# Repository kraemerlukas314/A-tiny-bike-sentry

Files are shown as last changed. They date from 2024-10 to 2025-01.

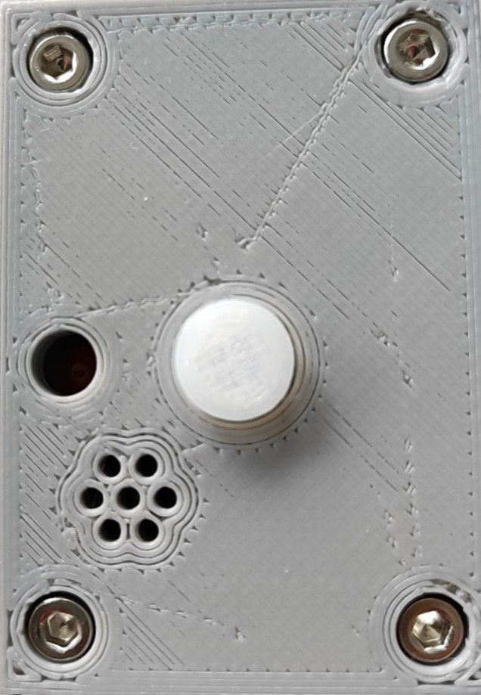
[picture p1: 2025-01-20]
docs/images/sentry.jpg

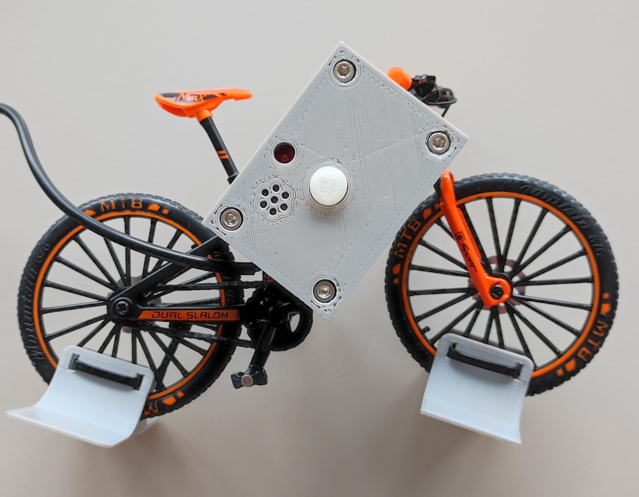
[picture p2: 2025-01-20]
docs/images/bike.jpg

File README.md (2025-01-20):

# A Tiny Bike Sentry

[🇩🇪 Deutsch](#-deutsch) | [🇬🇧 English](#-english)

---

## 📌 Deutsch

### Überblick
A Tiny Bike Sentry ist ein elektronisches Fahrradschloss, das bei Erschütterungen einen optischen und akustischen Alarm auslöst, um Diebstähle zu verhindern. Es basiert auf einem stromsparenden ATtiny85-Mikrocontroller und verwendet eine LED, einen Buzzer, einen Taster und einen Erschütterungssensor.

### Funktionen
- **Erschütterungserkennung**: Erkennt Bewegung mit einem Piezoelement und löst einen Alarm aus.
- **Akustische & optische Warnsignale**: Alarmiert mit einem Buzzer und einer LED.
- **Energiesparmodus**: Minimiert Stromverbrauch durch effiziente Software- und Hardwarearchitektur.
- **Manuelle Aktivierung**: Aktivierung und Deaktivierung per Knopfdruck.

### Hardware
- Mikrocontroller: **ATtiny85** (niedriger Stromverbrauch, kompakte Größe)
- Sensoren: **Piezoelement** zur Erschütterungserkennung
- Aktoren: **LED und Buzzer** zur Alarmierung
- Stromversorgung: **Akku- oder Batteriebetrieb** (optimiert für lange Laufzeit)

### Software
Die Software wurde in **C++** geschrieben und basiert auf einer **zustandsbasierten Programmierung**.
Wichtige Dateien:
- [`main.ino`](src/main/main.ino): Hauptprogramm mit der Zustandsmaschine
- [`Gpio.h`](src/main/Gpio.h) / [`Gpio.cpp`](src/main/Gpio.cpp): Steuerung der Hardware-Pins
- [`Animation.h`](src/main/Animation.h) / [`Animation.cpp`](src/main/Animation.cpp): Verwaltung der LED- und Buzzer-Signale
- [`Timing.h`](src/main/Timing.h) / [`Timing.cpp`](src/main/Timing.cpp): Optimierung der Zeitsteuerung
- [`defines.h`](src/main/defines.h): Konfigurationsdatei mit Schwellenwerten & Pin-Belegung

### Zustandsdiagramm
Das System arbeitet mit einer **Finite State Machine**:
- **Deep Sleep**: Gerät inaktiv, wartet auf Aktivierung
- **Sentry**: Gerät ist scharfgestellt und prüft auf Erschütterungen
- **Attention**: Vorwarnung nach erster Erschütterung
- **Alarm**: Vollständiger Alarmmodus
- **Cooldown**: Nach einer bestimmten Zeit ohne weitere Bewegung geht das System zurück in den Sentry-Modus

(Siehe [`State Machine Graph.pdf`](docs/final%20pdfs/State%20Machine%20Graph.pdf) für visuelle Darstellung)

### Installation & Nutzung
#### Voraussetzungen
- **Arduino IDE oder CLI**
- **ATtiny85 Board-Treiber** (via Board Manager installieren)
- **Arduino as ISP Programmer**

#### Kompilieren & Hochladen
1. ATtiny85 als Board in der Arduino IDE auswählen
2. `Programmer: Arduino as ISP` einstellen
3. Sketch mit `Sketch -> Hochladen über Programmer` übertragen
4. Gerät mit Strom versorgen und testen

### Dokumentation
Detaillierte Informationen zur Implementierung sind in folgenden Dateien enthalten:
- [`Benutzerdokumentation.pdf`](docs/final%20pdfs/A%20tiny%20bike%20sentry%20-%20Benutzerdokumentation.pdf): Anleitung für Endnutzer
- [`Entwicklerdokumentation.pdf`](docs/final%20pdfs/A%20tiny%20bike%20sentry%20-%20Entwicklerdokumentation.pdf): Technische Details & Implementierung
- [`Doxygen refman.pdf`](docs/final%20pdfs/Doxygen%20refman.pdf): Generierte Code-Dokumentation
- [`Präsentation.pdf`](docs/final%20pdfs/A%20tiny%20bike%20sentry%20-%20Präsentation.pdf): Überblick und Projektvorstellung

### Weiterentwicklung
- Implementierung eines **Bluetooth-Moduls** zur Fernsteuerung
- **Akkubetrieb mit Ladeschaltung** für mehr Flexibilität
- **Erweiterte Sicherheitsmechanismen** (z. B. Code-Eingabe oder Smartphone-Authentifizierung)

### Lizenz
Dieses Projekt steht unter der **MIT-Lizenz** – freie Nutzung und Modifikation sind erlaubt.

---

## 📌 English

### Overview
A Tiny Bike Sentry is an electronic bike lock that triggers an optical and acoustic alarm when vibrations are detected, helping to prevent theft. It is based on a low-power ATtiny85 microcontroller and uses an LED, a buzzer, a button, and a vibration sensor.

### Features
- **Vibration detection**: Detects movement with a piezo element and triggers an alarm.
- **Acoustic & optical warning signals**: Alerts with a buzzer and LED.
- **Energy-saving mode**: Minimizes power consumption through an efficient software and hardware architecture.
- **Manual activation**: Activate and deactivate via a button press.

### Hardware
- Microcontroller: **ATtiny85** (low power consumption, compact size)
- Sensors: **Piezo element** for vibration detection
- Actuators: **LED and buzzer** for alarming
- Power supply: **Battery or rechargeable operation** (optimized for long battery life)

### Software
The software is written in **C++** and is based on a **state-based programming** approach.
Key files:
- [`main.ino`](src/main/main.ino): Main program with the state machine
- [`Gpio.h`](src/main/Gpio.h) / [`Gpio.cpp`](src/main/Gpio.cpp): Controls hardware pins
- [`Animation.h`](src/main/Animation.h) / [`Animation.cpp`](src/main/Animation.cpp): Manages LED and buzzer signals
- [`Timing.h`](src/main/Timing.h) / [`Timing.cpp`](src/main/Timing.cpp): Optimizes time control
- [`defines.h`](src/main/defines.h): Configuration file with thresholds & pin assignments

### State Diagram
The system operates with a **Finite State Machine**:
- **Deep Sleep**: Device is inactive, waiting for activation
- **Sentry**: Device is armed and checking for vibrations
- **Attention**: Pre-warning after initial vibration detection
- **Alarm**: Full alarm mode
- **Cooldown**: After a certain time without further movement, the system returns to the Sentry mode

(See [`State Machine Graph.pdf`](docs/final%20pdfs/State%20Machine%20Graph.pdf) for a visual representation)

### Installation & Usage
#### Requirements
- **Arduino IDE or CLI**
- **ATtiny85 board driver** (install via board manager)
- **Arduino as ISP programmer**

#### Compiling & Uploading
1. Select ATtiny85 as board in Arduino IDE
2. Set `Programmer: Arduino as ISP`
3. Upload the sketch using `Sketch -> Upload Using Programmer`
4. Power the device and test

### Documentation
Detailed implementation information can be found in the following files:
- [`Benutzerdokumentation.pdf`](docs/final%20pdfs/A%20tiny%20bike%20sentry%20-%20Benutzerdokumentation.pdf): User manual
- [`Entwicklerdokumentation.pdf`](docs/final%20pdfs/A%20tiny%20bike%20sentry%20-%20Entwicklerdokumentation.pdf): Technical details & implementation
- [`Doxygen refman.pdf`](docs/final%20pdfs/Doxygen%20refman.pdf): Generated code documentation
- [`Präsentation.pdf`](docs/final%20pdfs/A%20tiny%20bike%20sentry%20-%20Präsentation.pdf): Overview and project presentation

### License
This project is released under the **MIT License** – free to use and modify.

---

**Project by Lukas Krämer | Winter Semester 2024**  
[GitHub Repository](https://github.com/kraemerlukas314/A-tiny-bike-sentry)

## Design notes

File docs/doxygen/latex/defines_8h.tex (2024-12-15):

\doxysection{src/main/defines.h File Reference}
\hypertarget{defines_8h}{}\label{defines_8h}\index{src/main/defines.h@{src/main/defines.h}}

This file includes all important declarations and definitions.  

\doxysubsubsection*{Macros}
\begin{DoxyCompactItemize}
\item 
\#define \mbox{\hyperlink{defines_8h_ae70934b3338990d4a3faecf2ee172d92}{PIN\+\_\+\+LED}}~1
\begin{DoxyCompactList}\small\item\em Pin for the LED. \end{DoxyCompactList}\item 
\#define \mbox{\hyperlink{defines_8h_a3be8154d350ce65f5e6c1dfc284700af}{PIN\+\_\+\+BUTTON}}~2
\begin{DoxyCompactList}\small\item\em Pin for the button. \end{DoxyCompactList}\item 
\#define \mbox{\hyperlink{defines_8h_ad67197684098f7e8191189a49b5198cd}{PIN\+\_\+\+PIEZO}}~3
\begin{DoxyCompactList}\small\item\em Pin for the piezo. \end{DoxyCompactList}\item 
\#define \mbox{\hyperlink{defines_8h_a192ea8eaba652d29bfc08675edebb6a2}{PIN\+\_\+\+BUZZER}}~4
\begin{DoxyCompactList}\small\item\em Pin for the button. \end{DoxyCompactList}\item 
\#define \mbox{\hyperlink{defines_8h_a28a3e5097d1f1cac1cd73737434760dc}{CLOCK\+\_\+\+FREQ\+\_\+\+MHZ}}~1
\begin{DoxyCompactList}\small\item\em Selected clock frequency in MHz. \end{DoxyCompactList}\item 
\#define \mbox{\hyperlink{defines_8h_a5be5a63f189faba4da1c6f98d11310c6}{THRESHOLD\+\_\+\+PIEZO}}~30
\begin{DoxyCompactList}\small\item\em Threshold for piezo for movement detection. \end{DoxyCompactList}\item 
\#define \mbox{\hyperlink{defines_8h_ae8df221e4e5e1930a43fb7d2c3944665}{DELAY\+\_\+\+BUTTON\+\_\+\+DEBOUNCE\+\_\+\+MS}}~50
\begin{DoxyCompactList}\small\item\em Button debounce delay. \end{DoxyCompactList}\item 
\#define \mbox{\hyperlink{defines_8h_a253c5c57ad2d67b9d8b6ddb553dde09a}{ALARM\+\_\+\+TOGGLE\+\_\+\+FREQ}}~20
\begin{DoxyCompactList}\small\item\em Frequency for alarm. \end{DoxyCompactList}\item 
\#define \mbox{\hyperlink{defines_8h_a6cd671141c60a732c42f1ad79f1a5890}{DELAY\+\_\+\+PIEZO\+\_\+\+MOVED\+\_\+\+MS}}~500
\begin{DoxyCompactList}\small\item\em When piezo is moved, wait for DELAY\+\_\+\+PIEZO\+\_\+\+MOVED\+\_\+\+MS because it could be just a button press. \end{DoxyCompactList}\item 
\#define \mbox{\hyperlink{defines_8h_a9e1a2184797108f3fd67e0251343d960}{ATTENTION\+\_\+\+COOLDOWN\+\_\+\+MS}}~5000
\begin{DoxyCompactList}\small\item\em Cooldown after which state attention is left again. \end{DoxyCompactList}\item 
\#define \mbox{\hyperlink{defines_8h_a6b3c978dd2a7b246650bb233f2b8e942}{ALARM\+\_\+\+COOLDOWN\+\_\+\+MS}}~5000
\begin{DoxyCompactList}\small\item\em Cooldown after which state alarm is left again. \end{DoxyCompactList}\end{DoxyCompactItemize}

\doxysubsection{Detailed Description}
This file includes all important declarations and definitions. 

\begin{DoxyAuthor}{Author}
Lukas Krämer 
\end{DoxyAuthor}

Definition in file \mbox{\hyperlink{defines_8h_source}{defines.\+h}}.

\doxysubsection{Macro Definition Documentation}
\Hypertarget{defines_8h_a6b3c978dd2a7b246650bb233f2b8e942}\label{defines_8h_a6b3c978dd2a7b246650bb233f2b8e942} 
\index{defines.h@{defines.h}!ALARM\_COOLDOWN\_MS@{ALARM\_COOLDOWN\_MS}}
\index{ALARM\_COOLDOWN\_MS@{ALARM\_COOLDOWN\_MS}!defines.h@{defines.h}}
\doxysubsubsection{\texorpdfstring{ALARM\_COOLDOWN\_MS}{ALARM\_COOLDOWN\_MS}}
{\footnotesize\ttfamily \#define ALARM\+\_\+\+COOLDOWN\+\_\+\+MS~5000}

Cooldown after which state alarm is left again. 

Definition at line \mbox{\hyperlink{defines_8h_source_l00063}{63}} of file \mbox{\hyperlink{defines_8h_source}{defines.\+h}}.

\Hypertarget{defines_8h_a253c5c57ad2d67b9d8b6ddb553dde09a}\label{defines_8h_a253c5c57ad2d67b9d8b6ddb553dde09a} 
\index{defines.h@{defines.h}!ALARM\_TOGGLE\_FREQ@{ALARM\_TOGGLE\_FREQ}}
\index{ALARM\_TOGGLE\_FREQ@{ALARM\_TOGGLE\_FREQ}!defines.h@{defines.h}}
\doxysubsubsection{\texorpdfstring{ALARM\_TOGGLE\_FREQ}{ALARM\_TOGGLE\_FREQ}}
{\footnotesize\ttfamily \#define ALARM\+\_\+\+TOGGLE\+\_\+\+FREQ~20}

Frequency for alarm. 

Definition at line \mbox{\hyperlink{defines_8h_source_l00047}{47}} of file \mbox{\hyperlink{defines_8h_source}{defines.\+h}}.

\Hypertarget{defines_8h_a9e1a2184797108f3fd67e0251343d960}\label{defines_8h_a9e1a2184797108f3fd67e0251343d960} 
\index{defines.h@{defines.h}!ATTENTION\_COOLDOWN\_MS@{ATTENTION\_COOLDOWN\_MS}}
\index{ATTENTION\_COOLDOWN\_MS@{ATTENTION\_COOLDOWN\_MS}!defines.h@{defines.h}}
\doxysubsubsection{\texorpdfstring{ATTENTION\_COOLDOWN\_MS}{ATTENTION\_COOLDOWN\_MS}}
{\footnotesize\ttfamily \#define ATTENTION\+\_\+\+COOLDOWN\+\_\+\+MS~5000}

Cooldown after which state attention is left again. 

Definition at line \mbox{\hyperlink{defines_8h_source_l00058}{58}} of file \mbox{\hyperlink{defines_8h_source}{defines.\+h}}.

\Hypertarget{defines_8h_a28a3e5097d1f1cac1cd73737434760dc}\label{defines_8h_a28a3e5097d1f1cac1cd73737434760dc} 
\index{defines.h@{defines.h}!CLOCK\_FREQ\_MHZ@{CLOCK\_FREQ\_MHZ}}
\index{CLOCK\_FREQ\_MHZ@{CLOCK\_FREQ\_MHZ}!defines.h@{defines.h}}
\doxysubsubsection{\texorpdfstring{CLOCK\_FREQ\_MHZ}{CLOCK\_FREQ\_MHZ}}
{\footnotesize\ttfamily \#define CLOCK\+\_\+\+FREQ\+\_\+\+MHZ~1}

Selected clock frequency in MHz. 

Definition at line \mbox{\hyperlink{defines_8h_source_l00032}{32}} of file \mbox{\hyperlink{defines_8h_source}{defines.\+h}}.

\Hypertarget{defines_8h_ae8df221e4e5e1930a43fb7d2c3944665}\label{defines_8h_ae8df221e4e5e1930a43fb7d2c3944665} 
\index{defines.h@{defines.h}!DELAY\_BUTTON\_DEBOUNCE\_MS@{DELAY\_BUTTON\_DEBOUNCE\_MS}}
\index{DELAY\_BUTTON\_DEBOUNCE\_MS@{DELAY\_BUTTON\_DEBOUNCE\_MS}!defines.h@{defines.h}}
\doxysubsubsection{\texorpdfstring{DELAY\_BUTTON\_DEBOUNCE\_MS}{DELAY\_BUTTON\_DEBOUNCE\_MS}}
{\footnotesize\ttfamily \#define DELAY\+\_\+\+BUTTON\+\_\+\+DEBOUNCE\+\_\+\+MS~50}

Button debounce delay. 

Definition at line \mbox{\hyperlink{defines_8h_source_l00042}{42}} of file \mbox{\hyperlink{defines_8h_source}{defines.\+h}}.

\Hypertarget{defines_8h_a6cd671141c60a732c42f1ad79f1a5890}\label{defines_8h_a6cd671141c60a732c42f1ad79f1a5890} 
\index{defines.h@{defines.h}!DELAY\_PIEZO\_MOVED\_MS@{DELAY\_PIEZO\_MOVED\_MS}}
\index{DELAY\_PIEZO\_MOVED\_MS@{DELAY\_PIEZO\_MOVED\_MS}!defines.h@{defines.h}}
\doxysubsubsection{\texorpdfstring{DELAY\_PIEZO\_MOVED\_MS}{DELAY\_PIEZO\_MOVED\_MS}}
{\footnotesize\ttfamily \#define DELAY\+\_\+\+PIEZO\+\_\+\+MOVED\+\_\+\+MS~500}

When piezo is moved, wait for DELAY\+\_\+\+PIEZO\+\_\+\+MOVED\+\_\+\+MS because it could be just a button press. 

Definition at line \mbox{\hyperlink{defines_8h_source_l00053}{53}} of file \mbox{\hyperlink{defines_8h_source}{defines.\+h}}.

\Hypertarget{defines_8h_a3be8154d350ce65f5e6c1dfc284700af}\label{defines_8h_a3be8154d350ce65f5e6c1dfc284700af} 
\index{defines.h@{defines.h}!PIN\_BUTTON@{PIN\_BUTTON}}
\index{PIN\_BUTTON@{PIN\_BUTTON}!defines.h@{defines.h}}
\doxysubsubsection{\texorpdfstring{PIN\_BUTTON}{PIN\_BUTTON}}
{\footnotesize\ttfamily \#define PIN\+\_\+\+BUTTON~2}

Pin for the button. 

Definition at line \mbox{\hyperlink{defines_8h_source_l00017}{17}} of file \mbox{\hyperlink{defines_8h_source}{defines.\+h}}.

\Hypertarget{defines_8h_a192ea8eaba652d29bfc08675edebb6a2}\label{defines_8h_a192ea8eaba652d29bfc08675edebb6a2} 
\index{defines.h@{defines.h}!PIN\_BUZZER@{PIN\_BUZZER}}
\index{PIN\_BUZZER@{PIN\_BUZZER}!defines.h@{defines.h}}
\doxysubsubsection{\texorpdfstring{PIN\_BUZZER}{PIN\_BUZZER}}
{\footnotesize\ttfamily \#define PIN\+\_\+\+BUZZER~4}

Pin for the button. 

Definition at line \mbox{\hyperlink{defines_8h_source_l00027}{27}} of file \mbox{\hyperlink{defines_8h_source}{defines.\+h}}.

\Hypertarget{defines_8h_ae70934b3338990d4a3faecf2ee172d92}\label{defines_8h_ae70934b3338990d4a3faecf2ee172d92} 
\index{defines.h@{defines.h}!PIN\_LED@{PIN\_LED}}
\index{PIN\_LED@{PIN\_LED}!defines.h@{defines.h}}
\doxysubsubsection{\texorpdfstring{PIN\_LED}{PIN\_LED}}
{\footnotesize\ttfamily \#define PIN\+\_\+\+LED~1}

Pin for the LED. 

Definition at line \mbox{\hyperlink{defines_8h_source_l00012}{12}} of file \mbox{\hyperlink{defines_8h_source}{defines.\+h}}.

\Hypertarget{defines_8h_ad67197684098f7e8191189a49b5198cd}\label{defines_8h_ad67197684098f7e8191189a49b5198cd} 
\index{defines.h@{defines.h}!PIN\_PIEZO@{PIN\_PIEZO}}
\index{PIN\_PIEZO@{PIN\_PIEZO}!defines.h@{defines.h}}
\doxysubsubsection{\texorpdfstring{PIN\_PIEZO}{PIN\_PIEZO}}
{\footnotesize\ttfamily \#define PIN\+\_\+\+PIEZO~3}

Pin for the piezo. 

Definition at line \mbox{\hyperlink{defines_8h_source_l00022}{22}} of file \mbox{\hyperlink{defines_8h_source}{defines.\+h}}.

\Hypertarget{defines_8h_a5be5a63f189faba4da1c6f98d11310c6}\label{defines_8h_a5be5a63f189faba4da1c6f98d11310c6} 
\index{defines.h@{defines.h}!THRESHOLD\_PIEZO@{THRESHOLD\_PIEZO}}
\index{THRESHOLD\_PIEZO@{THRESHOLD\_PIEZO}!defines.h@{defines.h}}
\doxysubsubsection{\texorpdfstring{THRESHOLD\_PIEZO}{THRESHOLD\_PIEZO}}
{\footnotesize\ttfamily \#define THRESHOLD\+\_\+\+PIEZO~30}

Threshold for piezo for movement detection. 

Definition at line \mbox{\hyperlink{defines_8h_source_l00037}{37}} of file \mbox{\hyperlink{defines_8h_source}{defines.\+h}}.

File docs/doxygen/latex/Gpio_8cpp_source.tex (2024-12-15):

\doxysection{Gpio.\+cpp}
\hypertarget{Gpio_8cpp_source}{}\label{Gpio_8cpp_source}\index{src/main/Gpio.cpp@{src/main/Gpio.cpp}}
\mbox{\hyperlink{Gpio_8cpp}{Go to the documentation of this file.}}
\begin{DoxyCode}{0}
\DoxyCodeLine{\Hypertarget{Gpio_8cpp_source_l00001}00001\ \textcolor{comment}{/**}}
\DoxyCodeLine{\Hypertarget{Gpio_8cpp_source_l00002}00002\ \textcolor{comment}{\ *\ @file\ Gpio.cpp}}
\DoxyCodeLine{\Hypertarget{Gpio_8cpp_source_l00003}00003\ \textcolor{comment}{\ *}}
\DoxyCodeLine{\Hypertarget{Gpio_8cpp_source_l00004}00004\ \textcolor{comment}{\ *\ Cpp\ file\ for\ Gpio\ class\ that\ provides}}
\DoxyCodeLine{\Hypertarget{Gpio_8cpp_source_l00005}00005\ \textcolor{comment}{\ *\ functions\ for\ direct\ hardware\ actions\ (e.g.\ turning\ on/off\ digital\ pins)}}
\DoxyCodeLine{\Hypertarget{Gpio_8cpp_source_l00006}00006\ \textcolor{comment}{\ *}}
\DoxyCodeLine{\Hypertarget{Gpio_8cpp_source_l00007}00007\ \textcolor{comment}{\ *\ @author\ Lukas\ Krämer}}
\DoxyCodeLine{\Hypertarget{Gpio_8cpp_source_l00008}00008\ \textcolor{comment}{\ */}}
\DoxyCodeLine{\Hypertarget{Gpio_8cpp_source_l00009}00009\ \textcolor{preprocessor}{\#pragma\ once}}
\DoxyCodeLine{\Hypertarget{Gpio_8cpp_source_l00010}00010\ }
\DoxyCodeLine{\Hypertarget{Gpio_8cpp_source_l00011}00011\ \textcolor{preprocessor}{\#include\ "{}\mbox{\hyperlink{Gpio_8h}{Gpio.h}}"{}}}
\DoxyCodeLine{\Hypertarget{Gpio_8cpp_source_l00012}00012\ }
\DoxyCodeLine{\Hypertarget{Gpio_8cpp_source_l00013}00013\ \textcolor{preprocessor}{\#include\ "{}Arduino.h"{}}}
\DoxyCodeLine{\Hypertarget{Gpio_8cpp_source_l00014}00014\ \textcolor{preprocessor}{\#include\ "{}\mbox{\hyperlink{Timing_8h}{Timing.h}}"{}}}
\DoxyCodeLine{\Hypertarget{Gpio_8cpp_source_l00015}00015\ \textcolor{preprocessor}{\#include\ "{}\mbox{\hyperlink{defines_8h}{defines.h}}"{}}}
\DoxyCodeLine{\Hypertarget{Gpio_8cpp_source_l00016}00016\ \textcolor{comment}{}}
\DoxyCodeLine{\Hypertarget{Gpio_8cpp_source_l00017}00017\ \textcolor{comment}{/**}}
\DoxyCodeLine{\Hypertarget{Gpio_8cpp_source_l00018}00018\ \textcolor{comment}{\ *\ Constructor\ for\ Timing\ class.}}
\DoxyCodeLine{\Hypertarget{Gpio_8cpp_source_l00019}00019\ \textcolor{comment}{\ *}}
\DoxyCodeLine{\Hypertarget{Gpio_8cpp_source_l00020}00020\ \textcolor{comment}{\ */}}
\DoxyCodeLine{\Hypertarget{Gpio_8cpp_source_l00021}\mbox{\hyperlink{classGpio_a51a72b41aabb6df62d8cb35f1b35849a}{00021}}\ \mbox{\hyperlink{classGpio_a51a72b41aabb6df62d8cb35f1b35849a}{Gpio::Gpio}}()\ :\ timing(\mbox{\hyperlink{defines_8h_a28a3e5097d1f1cac1cd73737434760dc}{CLOCK\_FREQ\_MHZ}})\ \{}
\DoxyCodeLine{\Hypertarget{Gpio_8cpp_source_l00022}00022\ \ \ \ \ pinMode(\mbox{\hyperlink{defines_8h_ae70934b3338990d4a3faecf2ee172d92}{PIN\_LED}},\ OUTPUT);}
\DoxyCodeLine{\Hypertarget{Gpio_8cpp_source_l00023}00023\ \ \ \ \ pinMode(\mbox{\hyperlink{defines_8h_a192ea8eaba652d29bfc08675edebb6a2}{PIN\_BUZZER}},\ OUTPUT);}
\DoxyCodeLine{\Hypertarget{Gpio_8cpp_source_l00024}00024\ \}}
\DoxyCodeLine{\Hypertarget{Gpio_8cpp_source_l00025}00025\ \textcolor{comment}{}}
\DoxyCodeLine{\Hypertarget{Gpio_8cpp_source_l00026}00026\ \textcolor{comment}{/**}}
\DoxyCodeLine{\Hypertarget{Gpio_8cpp_source_l00027}00027\ \textcolor{comment}{\ *\ GPIO\ setup\ function.}}
\DoxyCodeLine{\Hypertarget{Gpio_8cpp_source_l00028}00028\ \textcolor{comment}{\ *\ Sets\ all\ output\ pins\ as\ outputs.}}
\DoxyCodeLine{\Hypertarget{Gpio_8cpp_source_l00029}00029\ \textcolor{comment}{\ *}}
\DoxyCodeLine{\Hypertarget{Gpio_8cpp_source_l00030}00030\ \textcolor{comment}{\ */}}
\DoxyCodeLine{\Hypertarget{Gpio_8cpp_source_l00031}\mbox{\hyperlink{classGpio_a5bee528b0f527ee311016b90737b1a2e}{00031}}\ \textcolor{keywordtype}{void}\ \mbox{\hyperlink{classGpio_a5bee528b0f527ee311016b90737b1a2e}{Gpio::setup}}()\ \{}
\DoxyCodeLine{\Hypertarget{Gpio_8cpp_source_l00032}00032\ \ \ \ \ pinMode(\mbox{\hyperlink{defines_8h_ae70934b3338990d4a3faecf2ee172d92}{PIN\_LED}},\ OUTPUT);}
\DoxyCodeLine{\Hypertarget{Gpio_8cpp_source_l00033}00033\ \ \ \ \ pinMode(\mbox{\hyperlink{defines_8h_a192ea8eaba652d29bfc08675edebb6a2}{PIN\_BUZZER}},\ OUTPUT);}
\DoxyCodeLine{\Hypertarget{Gpio_8cpp_source_l00034}00034\ \}}
\DoxyCodeLine{\Hypertarget{Gpio_8cpp_source_l00035}00035\ \textcolor{comment}{}}
\DoxyCodeLine{\Hypertarget{Gpio_8cpp_source_l00036}00036\ \textcolor{comment}{/**}}
\DoxyCodeLine{\Hypertarget{Gpio_8cpp_source_l00037}00037\ \textcolor{comment}{\ *\ Turns\ on\ a\ pin.}}
\DoxyCodeLine{\Hypertarget{Gpio_8cpp_source_l00038}00038\ \textcolor{comment}{\ *}}
\DoxyCodeLine{\Hypertarget{Gpio_8cpp_source_l00039}00039\ \textcolor{comment}{\ *\ @param\ pin\ pin\ to\ turn\ on}}
\DoxyCodeLine{\Hypertarget{Gpio_8cpp_source_l00040}00040\ \textcolor{comment}{\ */}}
\DoxyCodeLine{\Hypertarget{Gpio_8cpp_source_l00041}\mbox{\hyperlink{classGpio_a8e7d8257872d8e9768e79ee92ccad76f}{00041}}\ \textcolor{keywordtype}{void}\ \mbox{\hyperlink{classGpio_a8e7d8257872d8e9768e79ee92ccad76f}{Gpio::on}}(\textcolor{keywordtype}{byte}\ pin)\ \{}
\DoxyCodeLine{\Hypertarget{Gpio_8cpp_source_l00042}00042\ \ \ \ \ digitalWrite(pin,\ HIGH);}
\DoxyCodeLine{\Hypertarget{Gpio_8cpp_source_l00043}00043\ \}}
\DoxyCodeLine{\Hypertarget{Gpio_8cpp_source_l00044}00044\ \textcolor{comment}{}}
\DoxyCodeLine{\Hypertarget{Gpio_8cpp_source_l00045}00045\ \textcolor{comment}{/**}}
\DoxyCodeLine{\Hypertarget{Gpio_8cpp_source_l00046}00046\ \textcolor{comment}{\ *\ Turns\ off\ a\ pin.}}
\DoxyCodeLine{\Hypertarget{Gpio_8cpp_source_l00047}00047\ \textcolor{comment}{\ *}}
\DoxyCodeLine{\Hypertarget{Gpio_8cpp_source_l00048}00048\ \textcolor{comment}{\ *\ @param\ pin\ pin\ to\ turn\ off}}
\DoxyCodeLine{\Hypertarget{Gpio_8cpp_source_l00049}00049\ \textcolor{comment}{\ */}}
\DoxyCodeLine{\Hypertarget{Gpio_8cpp_source_l00050}\mbox{\hyperlink{classGpio_aaa1d8c4c96c48c6635498dc265feb9f2}{00050}}\ \textcolor{keywordtype}{void}\ \mbox{\hyperlink{classGpio_aaa1d8c4c96c48c6635498dc265feb9f2}{Gpio::off}}(\textcolor{keywordtype}{byte}\ pin)\ \{}
\DoxyCodeLine{\Hypertarget{Gpio_8cpp_source_l00051}00051\ \ \ \ \ digitalWrite(pin,\ LOW);}
\DoxyCodeLine{\Hypertarget{Gpio_8cpp_source_l00052}00052\ \}}
\DoxyCodeLine{\Hypertarget{Gpio_8cpp_source_l00053}00053\ \textcolor{comment}{}}
\DoxyCodeLine{\Hypertarget{Gpio_8cpp_source_l00054}00054\ \textcolor{comment}{/**}}
\DoxyCodeLine{\Hypertarget{Gpio_8cpp_source_l00055}00055\ \textcolor{comment}{\ *\ Sets\ pin\ to\ state.}}
\DoxyCodeLine{\Hypertarget{Gpio_8cpp_source_l00056}00056\ \textcolor{comment}{\ *}}
\DoxyCodeLine{\Hypertarget{Gpio_8cpp_source_l00057}00057\ \textcolor{comment}{\ *\ @param\ pin\ pin\ to\ set\ state}}
\DoxyCodeLine{\Hypertarget{Gpio_8cpp_source_l00058}00058\ \textcolor{comment}{\ *\ @param\ state\ state\ to\ set\ (true/false)}}
\DoxyCodeLine{\Hypertarget{Gpio_8cpp_source_l00059}00059\ \textcolor{comment}{\ */}}
\DoxyCodeLine{\Hypertarget{Gpio_8cpp_source_l00060}\mbox{\hyperlink{classGpio_ad62c668ecc91f404fc7efc15833fecf8}{00060}}\ \textcolor{keywordtype}{void}\ \mbox{\hyperlink{classGpio_ad62c668ecc91f404fc7efc15833fecf8}{Gpio::set\_pin}}(\textcolor{keywordtype}{byte}\ pin,\ \textcolor{keywordtype}{bool}\ state)\ \{}
\DoxyCodeLine{\Hypertarget{Gpio_8cpp_source_l00061}00061\ \ \ \ \ digitalWrite(pin,\ state);}
\DoxyCodeLine{\Hypertarget{Gpio_8cpp_source_l00062}00062\ \}}
\DoxyCodeLine{\Hypertarget{Gpio_8cpp_source_l00063}00063\ \textcolor{comment}{}}
\DoxyCodeLine{\Hypertarget{Gpio_8cpp_source_l00064}00064\ \textcolor{comment}{/**}}
\DoxyCodeLine{\Hypertarget{Gpio_8cpp_source_l00065}00065\ \textcolor{comment}{\ *\ Function\ to\ toggle\ a\ digital\ pin\ on\ and\ off.}}
\DoxyCodeLine{\Hypertarget{Gpio_8cpp_source_l00066}00066\ \textcolor{comment}{\ *}}
\DoxyCodeLine{\Hypertarget{Gpio_8cpp_source_l00067}00067\ \textcolor{comment}{\ *\ @param\ pin\ Pin\ to\ toggle\ on\ and\ off}}
\DoxyCodeLine{\Hypertarget{Gpio_8cpp_source_l00068}00068\ \textcolor{comment}{\ *\ @param\ iterations\ How\ often\ should\ pin\ be\ toggled}}
\DoxyCodeLine{\Hypertarget{Gpio_8cpp_source_l00069}00069\ \textcolor{comment}{\ *\ @param\ d\ delay\ between\ of/off\ states\ (d\ =\ 1\ /\ frequency)}}
\DoxyCodeLine{\Hypertarget{Gpio_8cpp_source_l00070}00070\ \textcolor{comment}{\ */}}
\DoxyCodeLine{\Hypertarget{Gpio_8cpp_source_l00071}\mbox{\hyperlink{classGpio_a0d660b06ca9c13b5171d19c33ddad8ad}{00071}}\ \textcolor{keywordtype}{void}\ \mbox{\hyperlink{classGpio_a0d660b06ca9c13b5171d19c33ddad8ad}{Gpio::toggle}}(\textcolor{keywordtype}{byte}\ pin,\ \textcolor{keywordtype}{int}\ iterations,\ \textcolor{keywordtype}{long}\ d)\ \{}
\DoxyCodeLine{\Hypertarget{Gpio_8cpp_source_l00072}00072\ \ \ \ \ \textcolor{keywordflow}{for}\ (\textcolor{keywordtype}{int}\ i\ =\ 0;\ i\ <\ iterations;\ ++i)\ \{}
\DoxyCodeLine{\Hypertarget{Gpio_8cpp_source_l00073}00073\ \ \ \ \ \ \ \ \ digitalWrite(pin,\ HIGH);}
\DoxyCodeLine{\Hypertarget{Gpio_8cpp_source_l00074}00074\ \ \ \ \ \ \ \ \ \mbox{\hyperlink{classGpio_ad864b345067519caba07b12ce9425f05}{timing}}.\mbox{\hyperlink{classTiming_abb7d84af8a72cb2ed3d49127f3c7700c}{wait\_ms}}(d);}
\DoxyCodeLine{\Hypertarget{Gpio_8cpp_source_l00075}00075\ \ \ \ \ \ \ \ \ digitalWrite(pin,\ LOW);}
\DoxyCodeLine{\Hypertarget{Gpio_8cpp_source_l00076}00076\ \ \ \ \ \ \ \ \ \mbox{\hyperlink{classGpio_ad864b345067519caba07b12ce9425f05}{timing}}.\mbox{\hyperlink{classTiming_abb7d84af8a72cb2ed3d49127f3c7700c}{wait\_ms}}(d);}
\DoxyCodeLine{\Hypertarget{Gpio_8cpp_source_l00077}00077\ \ \ \ \ \}}
\DoxyCodeLine{\Hypertarget{Gpio_8cpp_source_l00078}00078\ \}}

\end{DoxyCode}

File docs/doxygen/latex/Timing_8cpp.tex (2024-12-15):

\doxysection{src/main/\+Timing.cpp File Reference}
\hypertarget{Timing_8cpp}{}\label{Timing_8cpp}\index{src/main/Timing.cpp@{src/main/Timing.cpp}}

Cpp file for \doxylink{classTiming}{Timing} class that provides corrected delay and millis functions based on selected clock frequency.  

{\ttfamily \#include "{}Timing.\+h"{}}\newline
{\ttfamily \#include "{}Arduino.\+h"{}}\newline

\doxysubsection{Detailed Description}
Cpp file for \doxylink{classTiming}{Timing} class that provides corrected delay and millis functions based on selected clock frequency. 

\begin{DoxyAuthor}{Author}
Lukas Krämer 
\end{DoxyAuthor}

Definition in file \mbox{\hyperlink{Timing_8cpp_source}{Timing.\+cpp}}.

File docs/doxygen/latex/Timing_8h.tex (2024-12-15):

\doxysection{src/main/\+Timing.h File Reference}
\hypertarget{Timing_8h}{}\label{Timing_8h}\index{src/main/Timing.h@{src/main/Timing.h}}

Header file for \doxylink{classTiming}{Timing} class.  

{\ttfamily \#include "{}Arduino.\+h"{}}\newline
\doxysubsubsection*{Data Structures}
\begin{DoxyCompactItemize}
\item 
class \mbox{\hyperlink{classTiming}{Timing}}
\begin{DoxyCompactList}\small\item\em \doxylink{classTiming}{Timing} class that provides corrected delay and millis functions based on selected clock frequency. \end{DoxyCompactList}\end{DoxyCompactItemize}

\doxysubsection{Detailed Description}
Header file for \doxylink{classTiming}{Timing} class. 

\begin{DoxyAuthor}{Author}
Lukas Krämer 
\end{DoxyAuthor}

Definition in file \mbox{\hyperlink{Timing_8h_source}{Timing.\+h}}.

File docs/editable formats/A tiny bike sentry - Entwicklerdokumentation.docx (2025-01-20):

Entwicklerdokumentation

A tiny bike sentry

WS 2024, Projekt Eingebettete Software

Lukas Krämer


Einführung

Fahrraddiebstahl stellte mit über 250.000 Delikten im vergangenen Jahr (Quelle 1) eine der weit verbreitetsten Straftaten in Deutschland dar, die aktuellen Präventivmaßnahmen gegen Diebstahl des eigenen Fahrrads reichen dabei von klassischen Schlössern bis hin zu Fahrrad-Sammelschließanlagen, wie sie sich beispielsweise an einigen Bahnstationen finden lassen. Gemeinsam haben dabei beide Lösungen, dass sie die Wahrscheinlichkeit des Diebstahls zwar erheblich senken, dafür aber auch verhältnismäßig unpraktisch und zum Teil auch mit hohen Kosten bzw. Abomodellen verbunden sind. Oftmals würde allerdings ein einfaches akustisches Warnsignal beim unerlaubten Bewegen des Fahrrads reichen, um einen potentiellen Diebstahl zu verhindern. Insbesondere in solchen Fällen, in denen ein Fahrrad zwecks Bequemlichkeit gar nicht gegen Diebstahl gesichert wird. Die bewährten Maßnahmen, wie beispielsweise das Anschließen, könnten und sollten natürlich weiterhin genutzt werden.

In diesem Projekt wurde ein solches rein akustisches Fahrradschloss entwickelt, dass vom Fahrradbesitzer beim Hinterlassen seines Fahrrads manuell aktiviert werden muss und anschließend mittels eines Erschütterungssensors (Piezoelement) kontinuierlich prüft, ob eine Erschütterung und somit ein potentieller Diebstahl vorliegt. Ist dies der Fall, gibt das Gerät sowohl optische als auch akustische Warnsignale von sich, um den Dieb doch noch von der Straftat abzuhalten. Sollte der Alarm fälschlicherweise aktiviert werden (zum Beispiel aufgrund einer kräftigen Windböe), schaltet er sich nach einer gewissen Zeit ohne weitere Erschütterungen automatisch wieder ab, bis das Gerät erneut bewegt wird.

Hardware

Neben der Software, auf welcher der Fokus bei diesem Projekt lag und auf die an späterer Stelle noch näher eingegangen wird, bestand der Gesamtaufwand nichtsdestoweniger auch aus einem Hardwareteil.

Zum Einsatz für das eigentliche Fahrradschloss kam hier ein ATtiny85, der im Vergleich zu anderen Mikrocontrollern eine sehr geringe Stromaufnahme und kleinen Platzbedarf besitzt und sich daher ideal für das Projekt eignet, da es langfristig mittels Akkus oder Batterien betrieben werden soll. Zwar verfügt der Controller verglichen mit beispielsweise einem Arduino Nano oder Raspberry Pi Pico über wenig digitale Ein- und Ausgänge, Speicher und Rechenleistung, die aber für dieses kleine Projekt dennoch vollkommen ausreichend sind.

Für die Erkennung der Erschütterungen wurde ein Piezoelement verwendet, das unter mechanischer Verformung hohe Spannungsspitzen erzeugt, dabei aber erheblich weniger Strom (genauer gesagt: praktisch gar keinen!) benötigt als herkömmliche Beschleunigungssensoren mit I2C Schnittstelle, die sicherlich auch hätten verwendet werden können. Die Spannungsspitzen des Piezoelements entstehen auch bei leichten Erschütterungen, fallen jedoch entsprechend geringer aus. Für das Auslesen des Sensors wurde er an einen analogen Eingang des ATtinys angeschlossen, um die Eingangspins vor eventuell hohen Spannungen/Strömen zu schützen, wurde sicherheitshalber noch ein hoher 10k Ohm Widerstand in Reihe und parallel geschaltet (siehe Bild 1).

Zur Bedienung des Schlosses wird zudem noch ein klassischer Taster benötigt, der an 5V und mittels Pull-down Widerstand an einen digitalen Eingangspin des Mikrocontrollers angeschlossen wurde. Auf die eingebauten Pull-up Widerstände des Mikrocontrollers wurde hier bewusst verzichtet, da diese einen permanenten Stromfluss bedeutet hätten, was die gesamte Leistungsaufnahme der Schaltung im Standby Zustand unnötig erhöht hätte.

Für den tatsächlichen Alarm kommen außerdem noch eine rote LED und ein aktiver Buzzer zum Einsatz, die unabhängig voneinander über den ATtiny geschaltet werden können.

Da der ATtiny nicht direkt über USB programmiert werden kann, wurde auf der Platine für das Schloss noch ein Steckverbinder montiert, der eine ISP-Schnittstelle zu einem anderen Mikrocontroller bereitstellt. Als ISP-Programmer wurde ein Arduino Nano Every verwendet, den Schaltplan zu der Programmer-Platine ist in Bild xxx dargestellt.

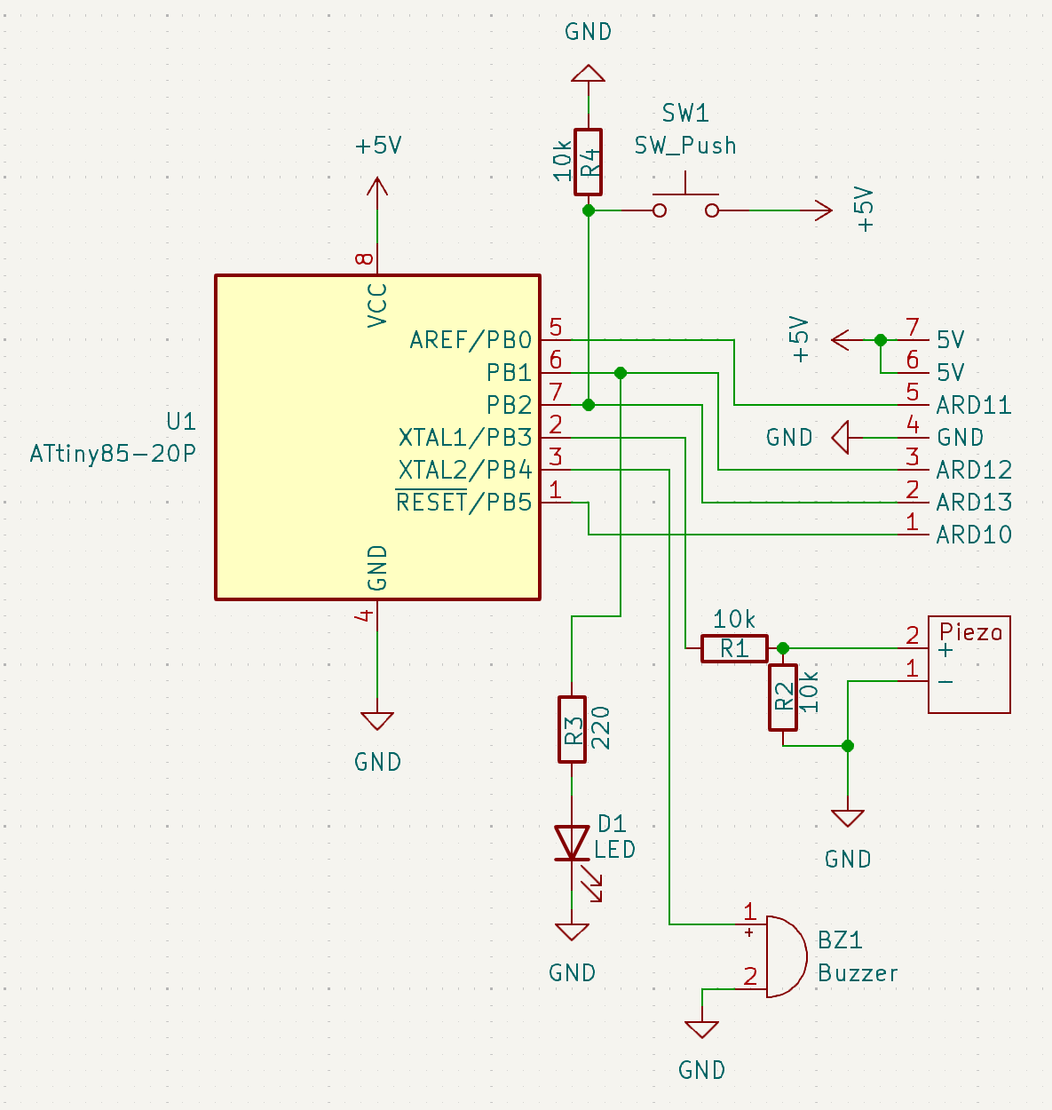
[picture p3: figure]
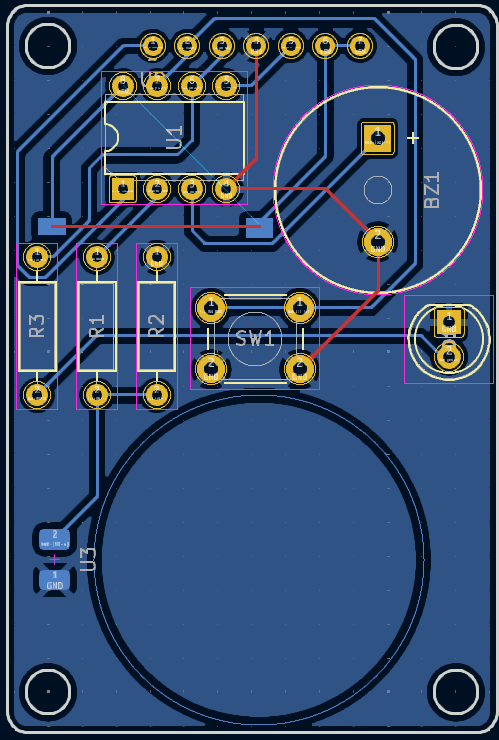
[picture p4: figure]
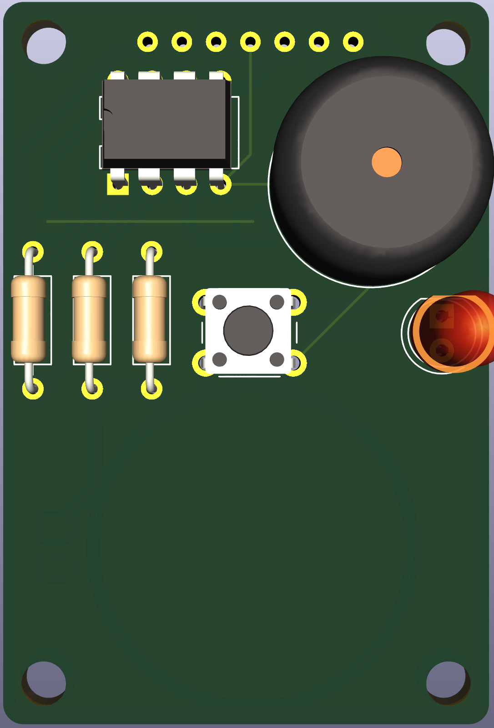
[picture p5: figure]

Bild 1: Schaltplan Bild 2: PCB Layout Bild3: PCB

Software

Ganz im Sinne des Modulnames „Eingebettete Software“ lag der Hauptfokus beim „Bike Sentry“ auf einer modularen und durchdachten Softwarearchitektur, die flexibel bezüglich späteren Veränderungen oder Ergänzungen sein sollte und dennoch gut lesbar, wartbar und strukturiert ist.

Zur Entwicklung wurde Visual Studio Code in Kombination mit dem Kommandozeilen-Tool Arduino CLI benutzt, um den geschriebenen Code für den ATtiny zu kompilieren und im Anschluss über den ISP-Programmer hochzuladen.

Wesentlicher Bestandteil des Codes ist die „main.ino“ Datei, in der die gesamte Programmlogik abgebildet ist. Hauptsächlich wird hier mit einem Aufzählungstyp (enum) gearbeitet, der die folgenden Zustände abspeichern kann:

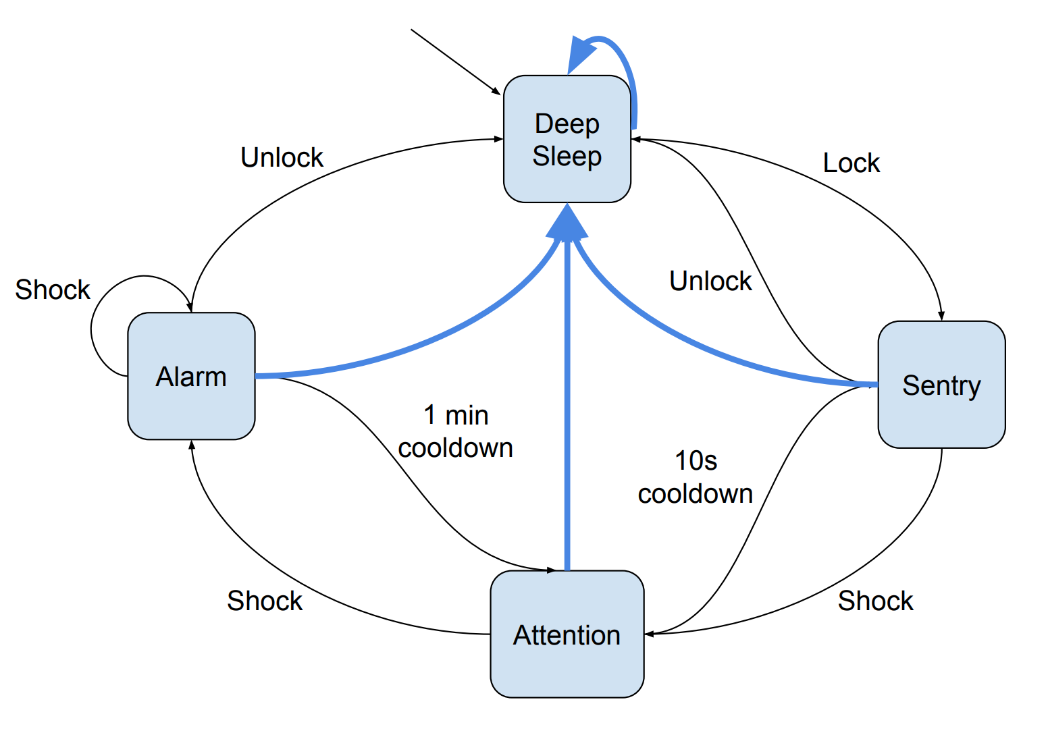
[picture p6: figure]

Bild 4: Zustandsgraph

Wie oben dargestellt, kann sich das Fahrradschloss in vier verschiedenen Zuständen befinden, zwischen denen teils manuell durch den Nutzer (Lock, Unlock per Tasterdruck), teils aber automatisch bei Erschütterungen (Shock) oder nach einer gewissen Zeit ohne weitere Erschütterungen (Cooldown) geschaltet wird. Nach dem Einschalten befindet sich das Gerät zunächst im Zustand „Deep Sleep“, in dem sich der ATtiny im Schlafmodus befindet und per Interrupt auf einen Tasterdruck wartet, was ihn in den Zustand „Sentry“ befördert. In diesem Zustand liest der Mikrocontroller permanent das Piezoelement aus, um potentielle Erschütterungen erkennen zu können. Falls dies der Fall ist, wird der Alarm allerdings noch nicht direkt gestartet, sondern das Gerät gelang zunächst in einen Zwischenzustand „Attention“ und löst erst nach einer weiteren Erschütterungen innerhalb der nächsten zehn Sekunden durch einen Wechsel in „Alarm“ den eigentlichen Alarm aus. Falls in dieser Zeitspanne keine weitere Erschütterung registriert wird, handelt es sich um einen Fehlalarm und es wird zurück in „Sentry“ gewechselt.

Im Alarmzustand gibt das Schloss sowohl optische als auch akustische Signale von sich, um auf den Diebstahl aufmerksam zu machen. Abgebrochen wird der Alarm nach einer Minute automatisch, andernfalls kann er auch jederzeit durch einen Knopfdruck manuell terminiert werden, da dieser einen Wechsel in den Zustand „Deep Sleep“ zur Folge hat. Dieses Verhalten, also dass ein Knopfdruck in anderen Zuständen als „Deep Sleep“ unmittelbar in ebendiesen Zustand wechselt, haben alle Zustände gemeinsam, um nicht zu Verwirrung zu führen und eine einfache Bedienung zu ermöglichen. In anderen Worten: ein Kopfdruck führt immer zu dem vorhersehbaren und gleichem Verhalten, unabhängig vom internen Zustand.

Der Vorteil dieser Programmarchitektur liegt hauptsächlich darin, dass sich jederzeit weitere Zustände ergänzen lassen, da diese in der Hauptschleife einfach mittels switch-Anweisung abgearbeitet werden. Dadurch war auch die Implementierung vergleichsweise einfach möglich, da zunächst die gesamte switch-Anweisung geschrieben und dann nach und nach das Verhalten in den Zuständen implementiert und separat getestet werden konnte.

Die Hauptdatei behandelt auch alle Formen von externem Input (Piezo und Taster) sowie die Implementierung der Schlafmodi und Interrupts. Diese wurden nicht in andere Dateien ausgelagert, da sie unmittelbaren Lese- und Schreibzugriff auf den globalen Aufzählungstyp für die Zustände benötigen und das Umherreichen von Zeigern auf diesen Typen die Les- und Wartbarkeit des Programms erheblich verschlechtern würde.

Was allerdings ausgelagert ist, sind alle Funktionen, die Ausgänge des ATtinys manipulieren, um die Hardware zumindest in Teilen von der Logik in der main-Datei zu trennen. Dafür wurde zunächst die Schnittstelle für die entsprechenden Funktionen in der Datei „Gpio.h“ festgelegt. Neben primitiven Funktionen wie „on“ und „off“, die jeweils einen übergebenden Pin Ein- bzw. Ausschalten können, gibt es noch „set_pin“ und „toggle“, die einen Pin auf einen Zustand (an, aus) setzen können bzw. einen Pin mit einer Periodendauer für eine bestimmte Anzahl an Vorgängen abwechselnd zwischen ein und aus schalten können.

Die genannten Funktionen sind in der „Gpio.cpp“ Datei nach der entsprechend definierten Schnittstelle implementiert.

Die Gpio Klasse ist dabei universell einsetzbar und kann theoretisch auch für andere Projekte in der Zukunft genutzt werden.

Im Gegensatz dazu steht die Animation Klasse, welche die Gpio Klasse nutzt, um Animationen für das Main-Programm bereitzustellen. Diese sind spezifisch auf dieses Projekt zugeschnitten und dienen dem Zweck, die hardwareseitigen Animationen nicht in „main.ino“ durchführen zu müssen, sondern getrennt von der Logik leicht anpassbare Animationen verwalten zu können. Die Klasse beinhaltet hauptsächlich Methoden, die vom Hauptprogramm beim Zustandswechsel aufgerufen werden können, zum Beispiel: exit_alarm(), welche die Animation beinhaltet, die beim Verlassen des Alarm Zustands abgespielt werden soll. Ähnlich aufgebaute Methoden gibt es auch für die anderen Zustände, mehr Informationen dazu sind in der doxygen Dokumentation zu finden.

Zu guter Letzt fasst die Bibliothek/Klasse „Timing“ angepasste Versionen der delay() und millis() Funktion zusammen. Diese sind nötig, weil der ATtiny hier lediglich mit einem MHz betrieben wird, um Strom zu sparen, die Standard-Taktfrequenz allerdings acht MHz beträgt. Daher wäre der gewöhnliche Aufruf von delay() oder millis() um Faktor acht falsch, was durch „Timing“ basierend auf der aktuell gewählten Taktfrequenz korrigiert wird. Diese kann dabei gemeinsam mit vielen anderen Einstellungen, wie genutzten Pins für Led, Buzzer oder Piezo, Schwellenwerten und Cooldown-Einstellungen, in der Datei „defines.h“ definiert werden.

Neben einer durchdachten Softwarearchitektur sollte auch ein Schlafmodus implementiert werden, dieser wurde hier mittels der der AVR sleep Bibliothek realisiert. Bevor der ATtiny in den „SLEEP_MODE_PWR_DOWN“ wechselt, werden der Analog zu Digital Konverter und Analog Komparator ausgeschaltet, um noch mehr Strom zu sparen. Dadurch konnte die Stromaufnahme im Schlafmodus auf 6,2µA reduziert werden, was selbst bei kleinen Akkus mit nur wenigen hundert mAh Kapazität für mehrere Jahre Akkulaufzeit ausreichen sollte. Aufwachen aus dem Schlafmodus erfolgt durch einen Pin-Interrupt durch den vom Nutzer gedrückten Taster.

Verbesserungspotential

Hardwareseitig sind soweit keine Probleme bekannt, allerdings wäre dauerhaft wünschenswert, wenn das Gerät auch portabel per Akku betrieben werden könnte. Dafür wäre beispielsweise ein kleiner (300mAh) LiPo mit passender Ladeelektronik (z.B. TP4056 oder TP5100) geeignet. Zudem kann der ATtiny auch mit Spannungen kleineren Spannungen als 5V betrieben werden (minimal 1,8V), was die Stromaufnahme um Faktor drei bis vier reduzieren würde. Allerdings würde die Platine dennoch eine zusätzliche 5V Spannungsversorgung benötigen, um im Falle eines Alarms den Buzzer und die LED einschalten zu können.

Darüber hinaus lässt sich der Alarm aktuell einfach per Knopfdruck deaktivieren, was langfristig nicht sonderlich sinnvoll wäre, da dies auch von einem Dieb erfolgen könnte. Gelöst werden könnte dieses Problem durch eine andere Art der Alarmdeaktivierung, wie beispielsweise einen Fingerabdrucksensor oder ein Bluetooth Modul, das die Anwesenheit des Smartphones vom Fahrradbesitzer erkennen kann und das Schloss dann automatisch entriegelt. Um zusätzlichen Hardwareaufwand zu vermeiden, könnte die Pin Eingabe jedoch auch über den bereits vorhandenen Kopf erfolgen. Diese könnte zum Beispiel im Morsecode erfolgen oder sich vollständig frei von Buchstaben und Zahlen konfigurieren lassen, so wäre unter anderem das „Klopfen“ einer Melodie als Entsperrmethode denkbar.

Was die Software betrifft, sind aktuell noch globale Variablen für Zeitstempel vorhanden, um die Animationen korrekt steuern zu können. Dies funktioniert soweit zwar, langfristig wäre es allerdings eleganter, die Zeitstempel intern im Animation Objekt mitzuverwalten.

Auch das Interrupt-Handling sowie die Methoden, um den ATtiny in den Schlafmodus zu versetzen bzw. wieder daraus zu wecken, könnten noch ausgelagert werden. Wie im Teil „Software“ näher beschrieben, würde dies jedoch dazu führen, dass Zeiger zum Aufzählungstypen, der den aktuellen Zustand verwaltet, übergeben werden müssten. Meiner Meinung nach verschlechtert dies die Les- und Wartbarkeit enorm, weshalb ich mich zunächst dagegen entschieden habe. Dadurch wird sichergestellt, dass Lese- und Schreiboperationen auf dem Aufzählungstypen nur im Hauptprogramm und nirgends sonst durchgeführt werden.

Zusätzlich ist die Tasterentprellung zwar soweit funktional, jedoch noch nicht perfekt gelöst, da ich zunächst bewusst auf statische/globale Variablen verzichten wollte, die für eine „richtige“ Tasterentprellung vonnöten wären

Wartung

Da im Projekt keine Servos oder Motoren verwendet wurden, sollte die mechanische Wartung vergleichsweise leicht sein. Die größte Schwachstelle stellen die beiden einzigen beweglichen Teile, der Buzzer und Taster, dar. Diese können im Laufe der Zeit verschmutzen oder sich abnutzen, was im Falle eines Defektes als Erstes kontrolliert werden sollte.

Zudem ist darauf zu achten, den Bike Sentry keinen großen mechanischen Belastungen auszusetzen, da sich die Lötstellen auf der Rückseite der Platine lösen könnten. Dies kann insbesondere nach einem Sturz der Fall sein und dazu führen, dass das Gerät augenscheinlich ganz defekt ist. Hier empfiehlt sich das vorsichtige Öffnen des Gehäuses und kontrollieren aller Lötstellen.

Weiterentwicklung

Entsprechende Weiterentwicklungen können gerne als Pull-Request im folgenden GitHub Repository hinzugefügt werden:

https://github.com/kraemerlukas314/A-tiny-bike-sentry

Auch Feature-Requests oder Bug-Reports können gerne auf gleiche Weise eingereicht werden.

Einrichten der Entwicklungsumgebung

Für die Entwicklung der Software kann prinzipiell ein beliebiger Text Editor genutzt werden. Besonders empfehlenswert ist jedoch die Arduino IDE, da hier der Code anwenderfreundlich auf den ATtiny hochgeladen werden kann. Dazu muss in den Einstellungen diese (https://raw.githubusercontent.com/damellis/attiny/ide-1.6.x-boards-manager/package_damellis_attiny_index.json) zusätzliche Board-URL hinzugefügt werden. Anschließend unter „Tools“ -> „Boards“ -> „Boardsmanager“ nach „ATtiny“ suchen und das Paket von „David A. Mellis“ installieren.

Nach einem Neustart der IDE kann nun unter „Tools“ -> „Board“ der ATtiny ausgewählt werden. Nun muss lediglich noch der Prozessor unter „Tools“ auf ATtiny85 gesetzt werden, zudem empfehle ich das Einstellen der Taktrate auf „Internal 1MHz“. Falls eine andere Taktrate gewünscht ist, muss diese außerdem in der Datei „defines.h“ angepasst werden, da ansonsten die delay() und millis() Funktionen nicht wie erwartet funktionieren.

Zum Hochladen muss nun der Arduino ISP Programmer an den PC angeschlossen werden. Falls dieser noch nicht die entsprechende Firmware besitzt, kann diese über „File“ -> „Examples“ -> „ArduinoISP“ -> „ArduinoISP“ auf das Board geflasht werden. Nun kann der ATtiny mit dem ISP Programmer verbunden werden. Damit das Hochladen funktioniert, ist zunächst der Port unter „Tools“ -> „Port“ korrekt auszuwählen, außerdem muss der Programmer, zu finden unter „Tools“ -> „Programmer“, auf „Arduino as ISP (ATmega32U4)“ gesetzt werden. Falls als ISP Programmer kein Arduino Nano Every, sondern ein Arduino Nano oder Uno verwendet werden möchte, ist die Option entsprechend auf den Eintrag „Arduino as ISP“ (also ohne ATmega32U4) zu setzen. Das Hochladen erfolgt jetzt wie gewohnt über den Upload-Button (Arduino IDE v1) oder über „Sketch“ -> „Upload using Programmer“ (Arduino IDE v2).

Falls auf die Nutzung der Arduino IDE verzichtet werden möchte, kann zum Hochladen auch das im Ordner „src/main“ hinterlegte Upload-Skript genutzt werden. Dieses gibt es sowohl als „.bat“ Version für Windows als auch als „.sh“ Datei für Linux/Unix basierte Systeme.

Hierzu muss allerdings noch Arduino CLI gemeinsam mit der additionalen Board-URL installiert werden, gegebenenfalls muss zusätzlich der Port im Skript selbst verändert werden. Dieser lässt sich unter Windows über den Gerätemanager und unter Linux mittels „ls /dev/tty*“ finden.

Teileliste

- 1x ATtiny85
- 1x aktiver Buzzer
- 1x rote LED
- 1x Taster
- 1x Arduino Nano Every
- Leiterplatte
- 1m dünnes Kabel
- 4x M3 Muttern
- 4x M3 Schrauben
- 30g Filament (z.B. PLA, PETG oder ABS)

Werkzeug

- Lötkolben
- Lötzinn
- 3D Drucker
- M3 Inbus

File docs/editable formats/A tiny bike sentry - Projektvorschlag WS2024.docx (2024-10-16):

Projekt-Vorschlag

Projekt: „A tiny“ bike sentry

Dokument: Projekt-Vorschlag PinkyPi WS2024

Version: 1.0.0

Datum: 16.10.2024

Status: vorläufig final

Zusammenfassung

In diesem Projekt wird ein Prototyp für eine Fahrrad-Alarmanlage entwickelt, die den Schutz vor Diebstahl verbessern soll. Sie setzt dabei auf eine modulare Softwarearchitektur und bietet eine Alternative bzw. Ergänzung zu herkömmlichen Lösungen wie Schlössern oder Fahrrad-Sammelschließanlagen.

1 Ziel

Das Hauptziel des Projektes besteht zunächst darin, einen funktionsfähigen Prototypen für die genannte Fahrrad Alarmanlage zu bauen, der (zumindest theoretisch...) effektiv vor Diebstahl schützen soll. Der Fokus liegt dabei auf der internen Softwarearchitektur, die möglichst modular mit Fokus auf einfache Wartbarkeit und potentielle Erweiterbarkeit sein sollte.

2 Ist-Situation

Fahrraddiebstahl stellte mit über 250.000 Delikten im vergangenen Jahr (Quelle 1) eine der weit verbreitetsten Straftaten in Deutschland dar, die aktuellen Präventivmaßnahmen gegen Diebstahl des eigenen Fahrrads reichen dabei von klassischen Schlössern bis hin zu Fahrrad-Sammelschließanlagen, wie sie sich beispielsweise an einigen Bahnstationen finden lassen. Gemeinsam haben dabei beide Lösungen, dass sie die Wahrscheinlichkeit des Diebstahls zwar erheblich senken, dafür aber auch verhältnismäßig unpraktisch und zum Teil auch mit hohen Kosten bzw. Abomodellen verbunden sind. Oftmals würde allerdings ein einfaches akustisches Warnsignal beim Unerlaubten Bewegen des Fahrrads reichen, um einen potentiellen Diebstahl zu verhindern. Insbesondere in solchen Fällen, in denen ein Fahrrad zwecks Bequemlichkeit gar nicht gegen Diebstahl gesichert wird. Die bewährten Maßnahmen, wie beispielsweise das Anschließen, könnten und sollten natürlich weiterhin genutzt werden.

3 Projekt-Ansatz

Der Fahrrad-Wächter besteht im Wesentlichen aus einer kleinen Plastikbox, die unauffällig am Fahrrad angebracht werden kann. Diese enthält einen Mikrocontroller und Erschütterungssensor sowie einen Lautsprecher und LEDs. Wird der Wächter vom Besitzer per Taster aktiviert, ertönen bei Erschütterung, die zum Beispiel durch unerlaubtes Bewegen des Fahrrads entstehen, akustische und visuelle Warnsignale, um einen potentiellen Diebstahl zu verhindern. Selbstverständlich kann der Alarm nur vom Besitzer ausgeschaltet werden, was langfristig beispielsweise durch die automatische Erkennung seines Smartphones oder einen Fingerabdrucksensor realisiert werden könnte, im ersten Prototyp allerdings durch einen einfachen Taster erfolgen wird.

4 Deliverables

Zum Projekt wird sowohl eine Entwickler- als auch Benutzerdoku verfasst, damit das Projekt genutzt und gewartet werden kann. Zusätzlich ist geplant, den Source Code und die Design-Dateien öffentlich auf GitHub zur Verfügung zu stellen, damit theoretisch auch andere an meinem Projekt weiterarbeiten können bzw. ich selbst jederzeit auf die Dateien zurückgreifen kann.
Das fertige Projekt wird außerdem in den Räumlichkeiten der FH ausgestellt werden, sodass es von Besuchern und anderen Studenten ausprobiert werden kann.

5 Material

Die für das Projekt benötigte Hardware ist in der folgenden Tabelle aufgelistet:

Bestellliste

Posten | Bezeichnung | Einzelpreis | Menge | Gesamtpreis | Bezugsquelle (Hyperlink)
1. | ATtiny85 | 3,79€ | 5 | 18,99€ | Amazon (https://www.amazon.de/dp/B0CLY1XKDB/)
2. | Piezo Element | 0,25€ | 20 | 4,99€ | Amazon (https://www.amazon.de/dp/B0BX46WMJH/)
3. | Buzzer | 0,35€ | 20 | 6,99€ | Amazon (https://www.amazon.de/dp/B0179I6LIK)
Optional | TP4056 | 1,16€ | 6 | 6,99€ | Amazon (https://www.amazon.de/dp/B0BZSB3SBN/)
Optional | 18650 Akku | 12,99€ | 1 | 12,99€ | Amazon (https://www.amazon.de/dp/B0D91WVVZ3)

6 Kosten

Wie der obigen Stückliste zu entnehmen ist, belaufen sich die initialen Kosten auf 30,97€ (50,95€ mit Akku und Ladeelektronik), wobei zusätzlich noch ein Arduino UNO/Nano (zum Programmieren des ATtiny), etwas Kupferkabel zum Löten sowie gängiges Werkzeug wie Lötkolben, Lötzinn und ein Schraubendreher benötigt werden. Zum Aufladen und Programmieren werden außerdem ein USB-C und Mini-USB Kabel benötigt.
Laufende Kosten fallen planmäßig keine an, selbst im Falle eines Defektes sind beispielsweise noch genügend Ersatzteile vorhanden.

7 Zeitliche Planung

Kalenderwoche | Phase | Todo
42 | Brainstorming, Projektvorschlag, Bestellung | Auf Idee festlegen, Teileliste erstellen, Projektvorschlag einreichen, Bestellung aufgeben
43 | Schaltplanentwurf, Recherche | Wartezeit auf Komponenten für Schaltplan und Recherche nutzen
44 | Hardwaretest | Hardwarekomponenten einzeln testen (insb. Piezo-Element an Oszilloskop. Entstehen hohe Spannungsspitzen?) Blink-LED Beispiel auf ATtiny, Hochladen per ISP testen, I2C Debugging testen
45 | Platine, Recherche | Platinenentwurf und Fertigung, Testen der Platine
46 | Software Überblick, Programm-Ablauf-Plan, Feedback | Was muss der Code tun? Wie muss er das tun? Wie ließe er sich in Zukunft erweitern? Welche Funktionen sind ähnlich zueinander und lassen sich zusammenfassen? Was davon kann in Bibliotheken ausgelagert werden? Wie kann der Code so entwickelt werden, dass er sich zunächst z.B. ohne Interrupt, Watchdog Timer und Deep Sleep nutzen lässt, diese Features später aber leicht ohne Architekturänderungen ergänzt werden können?
47 | Implementierung MVP & Feedback | Implementierung der generellen Architektur, Software sollte bereits funktionsfähig sein. Feedback holen!!!
48 | Verfeinerung der Software, Interrupt | Ggf. Verbessern der Architektur, Interrupt implementieren
49 | Watchdog Timer | Watchdog Timer implementieren
50 | Deep Sleep | Deep Sleep implementieren
51 | Code aufräumen | Auslagern, Kommentare ergänzen, Benennung von Variablen prüfen
52 | FERIEN | Puffer
1 | FERIEN | Puffer
2 | Dokumentation | Benutzer und Entwicklerdokumentation basierend auf Journal und Foto/Videomaterial erstellen
3 | Präsentation vorbereiten | Erstellung und üben der Präsentation
4 | Präsentation halten

8 Risiken

Das größte Risiko bei diesem Projekt liegt meiner Meinung nach darin, dass ich mir noch in keinem vorherigen Projekt solch fundierte Überlegungen zur Architektur gemacht habe, was die Zeiteinschätzung dieses vollständig neuen Themenbereiches schwierig macht. Entgegenzuwirken versuche ich daher dadurch, bereits von Anfang an Recherche in diesem Bereich zu betreiben und am Ende der Projektphase ausreichend Puffer einzuplanen, um das Projekt auf jeden Fall fristgerecht fertiggestellt zu bekommen.

9 Quellen

Quelle 1: Fahrraddiebstähle Deutschland 2023

WS2024 Name des Projekts: A tiny bike sentry 2024-10-16

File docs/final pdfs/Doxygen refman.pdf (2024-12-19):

## A tiny bike sentry

1.0

Generated on Wed Dec 18 2024 11:29:49 for A tiny bike sentry by Doxygen 1.9.8

Wed Dec 18 2024 11:29:49

i

1 Data Structure Index | 1
2 File Index | 3
3 Data Structure Documentation | 5

Generated on Wed Dec 18 2024 11:29:49 for A tiny bike sentry by Doxygen

ii

4 File Documentation | 15
Index | 27

# Chapter 1

# Data Structure Index

## 1.1 Data Structures

Here are the data structures with brief descriptions:

Animation

Gpio

Timing
Timing class that provides corrected delay and millis functions based on selected clock frequency 12

### 2 Data Structure Index

# Chapter 2

# File Index

## 2.1 File List

Here is a list of all documented files with brief descriptions:

src/main/Animation.cpp

src/main/Animation.h

src/main/defines.h

src/main/Gpio.cpp

src/main/Gpio.h

src/main/Timing.cpp
Cpp file for Timing class that provides corrected delay and millis functions based on selected

src/main/Timing.h

### 4 File Index

# Chapter 3

# Data Structure Documentation

## 3.1 Animation Class Reference

Animation class that provides functions for various animations (e.g.

#include <Animation.h>

Public Member Functions

- Animation ()

Constructor for Animation class.
- void enter_sentry ()

Animation to play when enterying sentry state.
- void enter_deep_sleep ()

Animation to play when enterying deep sleep state.
- void in_sentry ()

Animation to play when in sentry mode.
- void in_attention ()

Animation to play when in attention mode.
- void exit_alarm ()

Animation to play when exiting alarm mode.
- void in_alarm ()

Animation to play when in alarm mode.

Private Attributes

- Timing timing

Timing instance.
- Gpio gpio

GPIO instance.
- bool led_state

current led state in alarm

### 6 Data Structure Documentation

### 3.1.1 Detailed Description

Animation class that provides functions for various animations (e.g.

when switching states)

Definition at line 20 of file Animation.h.

### 3.1.2 Constructor & Destructor Documentation

### 3.1.2.1 Animation()

Animation::Animation ( )

Constructor for Animation class.

Definition at line 21 of file Animation.cpp.

References gpio, led_state, and Gpio::setup().

### 3.1.3 Member Function Documentation

### 3.1.3.1 enter_deep_sleep()

void Animation::enter_deep_sleep ( )

Animation to play when enterying deep sleep state.

Definition at line 38 of file Animation.cpp.

References gpio, PIN_LED, and Gpio::toggle().

### 3.1.3.2 enter_sentry()

void Animation::enter_sentry ( )

Animation to play when enterying sentry state.

Definition at line 30 of file Animation.cpp.

References gpio, PIN_LED, and Gpio::toggle().

### 3.1.3.3 exit_alarm()

void Animation::exit_alarm ( )

Animation to play when exiting alarm mode.

Definition at line 62 of file Animation.cpp.

References gpio, Gpio::off(), PIN_BUZZER, and PIN_LED.

3.1 Animation Class Reference | 7

### 3.1.3.4 in_alarm()

void Animation::in_alarm ( )

Animation to play when in alarm mode.

Definition at line 71 of file Animation.cpp.

References gpio, led_state, PIN_BUZZER, PIN_LED, and Gpio::set_pin().

### 3.1.3.5 in_attention()

void Animation::in_attention ( )

Animation to play when in attention mode.

Definition at line 54 of file Animation.cpp.

References gpio, Gpio::on(), and PIN_LED.

### 3.1.3.6 in_sentry()

void Animation::in_sentry ( )

Animation to play when in sentry mode.

Definition at line 46 of file Animation.cpp.

References gpio, Gpio::off(), and PIN_LED.

### 3.1.4 Field Documentation

### 3.1.4.1 gpio

Gpio Animation::gpio [private]

GPIO instance.

Definition at line 32 of file Animation.h.

Referenced by Animation(), enter_deep_sleep(), enter_sentry(), exit_alarm(), in_alarm(), in_attention(), and in_sentry().

### 3.1.4.2 led_state

bool Animation::led_state [private]

current led state in alarm

Definition at line 33 of file Animation.h.

Referenced by Animation(), and in_alarm().

### 8 Data Structure Documentation

### 3.1.4.3 timing

Timing Animation::timing [private]

Timing instance.

Definition at line 31 of file Animation.h.

The documentation for this class was generated from the following files:

- src/main/Animation.h
- src/main/Animation.cpp

## 3.2 Gpio Class Reference

Gpio class that provides functions for direct hardware actions (e.g.

#include <Gpio.h>

Public Member Functions

- Gpio ()

Constructor for Timing class.
- void setup ()

GPIO setup function.
- void on (byte pin)

Turns on a pin.
- void off (byte pin)

Turns off a pin.
- void set_pin (byte pin, bool state)

Sets pin to state.
- void toggle (byte pin, int iterations, long d)

Function to toggle a digital pin on and off.

Private Attributes

- Timing timing

Timing instance.

### 3.2.1 Detailed Description

Gpio class that provides functions for direct hardware actions (e.g.

turning on/off digital pins)

Definition at line 19 of file Gpio.h.

3.2 Gpio Class Reference | 9

### 3.2.2 Constructor & Destructor Documentation

### 3.2.2.1 Gpio()

Gpio::Gpio ( )

Constructor for Timing class.

Definition at line 21 of file Gpio.cpp.

References PIN_BUZZER, and PIN_LED.

### 3.2.3 Member Function Documentation

### 3.2.3.1 off()

void Gpio::off (

byte pin )

Turns off a pin.

Parameters

pin pin to turn off

Definition at line 50 of file Gpio.cpp.

Referenced by Animation::exit_alarm(), and Animation::in_sentry().

### 3.2.3.2 on()

void Gpio::on (

byte pin )

Turns on a pin.

Parameters

pin pin to turn on

Definition at line 41 of file Gpio.cpp.

Referenced by Animation::in_attention().

### 3.2.3.3 set_pin()

void Gpio::set_pin (

byte pin,

bool state )

### 10 Data Structure Documentation

Sets pin to state.

3.2 Gpio Class Reference | 11

Parameters

pin | pin to set state
state | state to set (true/false)

Definition at line 60 of file Gpio.cpp.

Referenced by Animation::in_alarm().

### 3.2.3.4 setup()

void Gpio::setup ( )

GPIO setup function.

Sets all output pins as outputs.

Definition at line 31 of file Gpio.cpp.

References PIN_BUZZER, and PIN_LED.

Referenced by Animation::Animation().

### 3.2.3.5 toggle()

void Gpio::toggle (

byte pin,

int iterations,

long d )

Function to toggle a digital pin on and off.

Parameters

pin | Pin to toggle on and off
iterations | How often should pin be toggled
d | delay between of/off states (d = 1 / frequency)

Definition at line 71 of file Gpio.cpp.

References timing, and Timing::wait_ms().

Referenced by Animation::enter_deep_sleep(), and Animation::enter_sentry().

### 3.2.4 Field Documentation

### 3.2.4.1 timing

Timing Gpio::timing [private]

### 12 Data Structure Documentation

Timing instance.

Definition at line 29 of file Gpio.h.

Referenced by toggle().

The documentation for this class was generated from the following files:

- src/main/Gpio.h
- src/main/Gpio.cpp

## 3.3 Timing Class Reference

Timing class that provides corrected delay and millis functions based on selected clock frequency.

#include <Timing.h>

Public Member Functions

- Timing (byte clock_freq_mhz)

Constructor for Timing class.
- void wait_ms (long d)

Own delay function that counteracts different clock speeds.
- long long get_millis ()

Own millis function that counteracts different clock speeds.

Private Attributes

- byte this_clock_freq_mhz

selected clock frequency

### 3.3.1 Detailed Description

Timing class that provides corrected delay and millis functions based on selected clock frequency.

Definition at line 17 of file Timing.h.

### 3.3.2 Constructor & Destructor Documentation

### 3.3.2.1 Timing()

Timing::Timing (

byte clock_freq_mhz )

Constructor for Timing class.

3.3 Timing Class Reference | 13

Parameters

clock_freq_mhz selected clock frequency.

Definition at line 20 of file Timing.cpp.

References this_clock_freq_mhz.

### 3.3.3 Member Function Documentation

### 3.3.3.1 get_millis()

long long Timing::get_millis ( )

Own millis function that counteracts different clock speeds.

Returns

long millis since ATtiny restart

Definition at line 43 of file Timing.cpp.

References this_clock_freq_mhz.

### 3.3.3.2 wait_ms()

void Timing::wait_ms (

long duration )

Own delay function that counteracts different clock speeds.

Parameters

duration delay time in ms

Definition at line 29 of file Timing.cpp.

References this_clock_freq_mhz.

Referenced by Gpio::toggle().

### 3.3.4 Field Documentation

### 3.3.4.1 this_clock_freq_mhz

byte Timing::this_clock_freq_mhz [private]

### 14 Data Structure Documentation

selected clock frequency

Definition at line 24 of file Timing.h.

Referenced by get_millis(), Timing(), and wait_ms().

The documentation for this class was generated from the following files:

- src/main/Timing.h
- src/main/Timing.cpp

# Chapter 4

# File Documentation

## 4.1 src/main/Animation.cpp File Reference

Cpp file for Animation class that provides functions for various animations (e.g.

#include "Animation.h"

#include "Arduino.h"

#include "Gpio.h"

#include "Timing.h"

#include "defines.h"

### 4.1.1 Detailed Description

Cpp file for Animation class that provides functions for various animations (e.g.

when switching states)

Author

Lukas Krämer

Definition in file Animation.cpp.

## 4.2 Animation.cpp

Go to the documentation of this file.

00001 /**
00002 | * @file Animation.cpp
00003 | *
00004 | * Cpp file for Animation class that provides
00005 | * functions for various animations (e.g. when switching states)
00006 | *
00007 | * @author Lukas Krämer
00008 | */
00009 #pragma once
00010
00011 #include "Animation.h" 00012

### 16 File Documentation

00013 #include "Arduino.h" 00014 #include "Gpio.h"
00015 #include "Timing.h"
00016 #include "defines.h"
00017
00018 /**
00019 | * Constructor for Animation class.
00020 | */
00021 Animation::Animation() : timing(CLOCK_FREQ_MHZ), gpio() {
00022 | gpio.setup();
00023 | led_state = false;
00024 }
00025
00026 /**
00027 | * Animation to play when enterying sentry state.
00028 | *
00029 | */
00030 void Animation::enter_sentry() {
00031 | gpio.toggle(PIN_LED, 3, 100);
00032 }
00033
00034 /**
00035 | * Animation to play when enterying deep sleep state.
00036 | *
00037 | */
00038 void Animation::enter_deep_sleep() {
00039 | gpio.toggle(PIN_LED, 2, 400);
00040 }
00041
00042 /**
00043 | * Animation to play when in sentry mode.
00044 | *
00045 | */
00046 void Animation::in_sentry() {
00047 | gpio.off(PIN_LED);
00048 }
00049
00050 /**
00051 | * Animation to play when in attention mode.
00052 | *
00053 | */
00054 void Animation::in_attention() {
00055 | gpio.on(PIN_LED);
00056 }
00057
00058 /**
00059 | * Animation to play when exiting alarm mode.
00060 | *
00061 | */
00062 void Animation::exit_alarm() {
00063 | gpio.off(PIN_LED);
00064 | gpio.off(PIN_BUZZER);
00065 }
00066
00067 /**
00068 | * Animation to play when in alarm mode.
00069 | *
00070 | */
00071 void Animation::in_alarm() {
00072 | gpio.set_pin(PIN_LED, led_state);
00073 | gpio.set_pin(PIN_BUZZER, !led_state);
00074 | led_state = !led_state;
00075 }

## 4.3 src/main/Animation.h File Reference

Header file for Animation class.

#include "Arduino.h"

#include "Gpio.h"

#include "Timing.h"

#include "defines.h"

Data Structures

- class Animation

Animation class that provides functions for various animations (e.g.

4.4 Animation.h | 17

### 4.3.1 Detailed Description

Header file for Animation class.

Author

Lukas Krämer

Definition in file Animation.h.

## 4.4 Animation.h

Go to the documentation of this file.

00001 /**
00002 | * @file Animation.h
00003 | *
00004 | * Header file for Animation class
00005 | *
00006 | * @author Lukas Krämer
00007 | */
00008 #pragma once
00009
00010 #include "Arduino.h" 00011 #include "Gpio.h"
00012 #include "Timing.h"
00013 #include "defines.h"
00014
00015 /**
00016 | * Animation class that provides
00017 | * functions for various animations (e.g. when switching states)
00018 | *
00019 | */
00020 class Animation {
00021 | public:
00022 | Animation();
00023 | void enter_sentry();
00024 | void enter_deep_sleep();
00025 | void in_sentry();
00026 | void in_attention();
00027 | void exit_alarm();
00028 | void in_alarm();
00029
00030 | private:
00031 | Timing timing; | ///< Timing instance
00032 | Gpio gpio; | ///< GPIO instance
00033 | bool led_state; | ///< current led state in alarm
00034 };

## 4.5 src/main/defines.h File Reference

This file includes all important declarations and definitions.

Macros

- #define PIN_LED 1

Pin for the LED.
- #define PIN_BUTTON 2

Pin for the button.
- #define PIN_PIEZO 3

Pin for the piezo.
- #define PIN_BUZZER 4

### 18 File Documentation

Pin for the button.
- #define CLOCK_FREQ_MHZ 1

Selected clock frequency in MHz.
- #define THRESHOLD_PIEZO 30

Threshold for piezo for movement detection.
- #define DELAY_BUTTON_DEBOUNCE_MS 50

Button debounce delay.
- #define ALARM_TOGGLE_FREQ 20

Frequency for alarm.
- #define DELAY_PIEZO_MOVED_MS 500

When piezo is moved, wait for DELAY_PIEZO_MOVED_MS because it could be just a button press.
- #define ATTENTION_COOLDOWN_MS 5000

Cooldown after which state attention is left again.
- #define ALARM_COOLDOWN_MS 5000

Cooldown after which state alarm is left again.

### 4.5.1 Detailed Description

This file includes all important declarations and definitions.

Author

Lukas Krämer

Definition in file defines.h.

### 4.5.2 Macro Definition Documentation

### 4.5.2.1 ALARM_COOLDOWN_MS

#define ALARM_COOLDOWN_MS 5000

Cooldown after which state alarm is left again.

Definition at line 63 of file defines.h.

### 4.5.2.2 ALARM_TOGGLE_FREQ

#define ALARM_TOGGLE_FREQ 20

Frequency for alarm.

Definition at line 47 of file defines.h.

### 4.5.2.3 ATTENTION_COOLDOWN_MS

#define ATTENTION_COOLDOWN_MS 5000

Cooldown after which state attention is left again.

Definition at line 58 of file defines.h.

4.5 src/main/defines.h File Reference | 19

### 4.5.2.4 CLOCK_FREQ_MHZ

#define CLOCK_FREQ_MHZ 1

Selected clock frequency in MHz.

Definition at line 32 of file defines.h.

### 4.5.2.5 DELAY_BUTTON_DEBOUNCE_MS

#define DELAY_BUTTON_DEBOUNCE_MS 50

Button debounce delay.

Definition at line 42 of file defines.h.

### 4.5.2.6 DELAY_PIEZO_MOVED_MS

#define DELAY_PIEZO_MOVED_MS 500

When piezo is moved, wait for DELAY_PIEZO_MOVED_MS because it could be just a button press.

Definition at line 53 of file defines.h.

### 4.5.2.7 PIN_BUTTON

#define PIN_BUTTON 2

Pin for the button.

Definition at line 17 of file defines.h.

### 4.5.2.8 PIN_BUZZER

#define PIN_BUZZER 4

Pin for the button.

Definition at line 27 of file defines.h.

### 4.5.2.9 PIN_LED

#define PIN_LED 1

Pin for the LED.

Definition at line 12 of file defines.h.

### 20 File Documentation

### 4.5.2.10 PIN_PIEZO

#define PIN_PIEZO 3

Pin for the piezo.

Definition at line 22 of file defines.h.

### 4.5.2.11 THRESHOLD_PIEZO

#define THRESHOLD_PIEZO 30

Threshold for piezo for movement detection.

Definition at line 37 of file defines.h.

## 4.6 defines.h

Go to the documentation of this file.

00001 /**
00002 | * @file defines.h
00003 | *
00004 | * This file includes all important declarations and definitions.
00005 | *
00006 | * @author Lukas Krämer
00007 | */
00008
00009 /**
00010 | * @brief Pin for the LED.
00011 | */
00012 #define PIN_LED 1
00013
00014 /**
00015 | * @brief Pin for the button.
00016 | */
00017 #define PIN_BUTTON 2
00018
00019 /**
00020 | * @brief Pin for the piezo.
00021 | */
00022 #define PIN_PIEZO 3
00023
00024 /**
00025 | * @brief Pin for the button.
00026 | */
00027 #define PIN_BUZZER 4
00028
00029 /**
00030 | * @brief Selected clock frequency in MHz.
00031 | */
00032 #define CLOCK_FREQ_MHZ 1
00033
00034 /**
00035 | * @brief Threshold for piezo for movement detection.
00036 | */
00037 #define THRESHOLD_PIEZO 30
00038
00039 /**
00040 | * @brief Button debounce delay.
00041 | */
00042 #define DELAY_BUTTON_DEBOUNCE_MS 50 00043
00044 /**
00045 | * @brief Frequency for alarm.
00046 | */
00047 #define ALARM_TOGGLE_FREQ 20
00048
00049 /**
00050 | * @brief When piezo is moved, wait
00051 | * for DELAY_PIEZO_MOVED_MS because it could be just a button press.
00052 | */

4.7 src/main/Gpio.cpp File Reference | 21

00053 #define DELAY_PIEZO_MOVED_MS 500
00054
00055 /**
00056 | * @brief Cooldown after which state attention is left again.
00057 | */
00058 #define ATTENTION_COOLDOWN_MS 5000
00059
00060 /**
00061 | * @brief Cooldown after which state alarm is left again.
00062 | */
00063 #define ALARM_COOLDOWN_MS 5000

## 4.7 src/main/Gpio.cpp File Reference

Cpp file for Gpio class that provides functions for direct hardware actions (e.g.

#include "Gpio.h"

#include "Arduino.h"

#include "Timing.h"

#include "defines.h"

### 4.7.1 Detailed Description

Cpp file for Gpio class that provides functions for direct hardware actions (e.g.

turning on/off digital pins)

Author

Lukas Krämer

Definition in file Gpio.cpp.

## 4.8 Gpio.cpp

Go to the documentation of this file.

00001 /**
00002 | * @file Gpio.cpp
00003 | *
00004 | * Cpp file for Gpio class that provides
00005 | * functions for direct hardware actions (e.g. turning on/off digital pins)
00006 | *
00007 | * @author Lukas Krämer
00008 | */
00009 #pragma once
00010
00011 #include "Gpio.h"
00012
00013 #include "Arduino.h" 00014 #include "Timing.h"
00015 #include "defines.h"
00016
00017 /**
00018 | * Constructor for Timing class.
00019 | *
00020 | */
00021 Gpio::Gpio() : timing(CLOCK_FREQ_MHZ) {
00022 | pinMode(PIN_LED, OUTPUT);
00023 | pinMode(PIN_BUZZER, OUTPUT);
00024 }
00025

### 22 File Documentation

00026 /**
00027 | * GPIO setup function.
00028 | * Sets all output pins as outputs.
00029 | *
00030 | */
00031 void Gpio::setup() {
00032 | pinMode(PIN_LED, OUTPUT);
00033 | pinMode(PIN_BUZZER, OUTPUT);
00034 }
00035
00036 /**
00037 | * Turns on a pin.
00038 | *
00039 | * @param pin pin to turn on
00040 | */
00041 void Gpio::on(byte pin) {
00042 | digitalWrite(pin, HIGH);
00043 }
00044
00045 /**
00046 | * Turns off a pin.
00047 | *
00048 | * @param pin pin to turn off
00049 | */
00050 void Gpio::off(byte pin) {
00051 | digitalWrite(pin, LOW);
00052 }
00053
00054 /**
00055 | * Sets pin to state.
00056 | *
00057 | * @param pin pin to set state
00058 | * @param state state to set (true/false)
00059 | */
00060 void Gpio::set_pin(byte pin, bool state) {
00061 | digitalWrite(pin, state);
00062 }
00063
00064 /**
00065 | * Function to toggle a digital pin on and off.
00066 | *
00067 | * @param pin Pin to toggle on and off
00068 | * @param iterations How often should pin be toggled
00069 | * @param d delay between of/off states (d = 1 / frequency)
00070 | */
00071 void Gpio::toggle(byte pin, int iterations, long d) {
00072 | for (int i = 0; i < iterations; ++i) {
00073 | digitalWrite(pin, HIGH);
00074 | timing.wait_ms(d);
00075 | digitalWrite(pin, LOW);
00076 | timing.wait_ms(d);
00077 | }
00078 }

## 4.9 src/main/Gpio.h File Reference

Header file for Gpio class.

#include "Arduino.h"

#include "Timing.h"

#include "defines.h"

Data Structures

- class Gpio

Gpio class that provides functions for direct hardware actions (e.g.

4.10 Gpio.h | 23

### 4.9.1 Detailed Description

Header file for Gpio class.

Author

Lukas Krämer

Definition in file Gpio.h.

## 4.10 Gpio.h

Go to the documentation of this file.

00001 /**
00002 | * @file Gpio.h
00003 | *
00004 | * Header file for Gpio class
00005 | *
00006 | * @author Lukas Krämer
00007 | */
00008 #pragma once
00009
00010 #include "Arduino.h" 00011 #include "Timing.h"
00012 #include "defines.h"
00013
00014 /**
00015 | * Gpio class that provides
00016 | * functions for direct hardware actions (e.g. turning on/off digital pins)
00017 | *
00018 | */
00019 class Gpio {
00020 | public:
00021 | Gpio();
00022 | void setup();
00023 | void on(byte pin);
00024 | void off(byte pin);
00025 | void set_pin(byte pin, bool state);
00026 | void toggle(byte pin, int iterations, long d);
00027
00028 | private:
00029 | Timing timing; | ///< Timing instance
00030 };

## 4.11 src/main/Timing.cpp File Reference

Cpp file for Timing class that provides corrected delay and millis functions based on selected clock frequency.

#include "Timing.h"

#include "Arduino.h"

### 4.11.1 Detailed Description

Cpp file for Timing class that provides corrected delay and millis functions based on selected clock frequency.

Author

Lukas Krämer

Definition in file Timing.cpp.

### 24 File Documentation

## 4.12 Timing.cpp

Go to the documentation of this file.

00001 /**
00002 | * @file Timing.cpp
00003 | *
00004 | * Cpp file for Timing class that provides corrected
00005 | * delay and millis functions based on selected clock frequency.
00006 | *
00007 | * @author Lukas Krämer
00008 | */
00009 #pragma once
00010
00011 #include "Timing.h"
00012
00013 #include "Arduino.h"
00014
00015 /**
00016 | * Constructor for Timing class.
00017 | *
00018 | * @param clock_freq_mhz selected clock frequency.
00019 | */
00020 Timing::Timing(byte clock_freq_mhz) {
00021 | this_clock_freq_mhz = clock_freq_mhz;
00022 }
00023
00024 /**
00025 | * Own delay function that counteracts different clock speeds.
00026 | *
00027 | * @param duration delay time in ms
00028 | */
00029 void Timing::wait_ms(long duration) {
00030 | if (this_clock_freq_mhz == 1)
00031 | delay(duration * 8);
00032 | else if (this_clock_freq_mhz == 8)
00033 | delay(duration);
00034 | else
00035 | delay(duration); | // Add options for external 16MHz here if needed
00036 }
00037
00038 /**
00039 | * Own millis function that counteracts different clock speeds.
00040 | *
00041 | * @return long millis since ATtiny restart
00042 | */
00043 long long Timing::get_millis() {
00044 | if (this_clock_freq_mhz == 1) return millis() / 8;
00045 | if (this_clock_freq_mhz == 8) return millis();
00046 }

## 4.13 src/main/Timing.h File Reference

Header file for Timing class.

#include "Arduino.h"

Data Structures

- class Timing

Timing class that provides corrected delay and millis functions based on selected clock frequency.

### 4.13.1 Detailed Description

Header file for Timing class.

Author

Lukas Krämer

Definition in file Timing.h.

4.14 Timing.h | 25

## 4.14 Timing.h

Go to the documentation of this file.

00001 /**
00002 | * @file Timing.h
00003 | *
00004 | * Header file for Timing class.
00005 | *
00006 | * @author Lukas Krämer
00007 | */
00008 #pragma once
00009
00010 #include "Arduino.h"
00011
00012 /**
00013 | * Timing class that provides corrected
00014 | * delay and millis functions based on selected clock frequency.
00015 | *
00016 | */
00017 class Timing {
00018 | public:
00019 | Timing(byte clock_freq_mhz);
00020 | void wait_ms(long d);
00021 | long long get_millis();
00022
00023 | private:
00024 | byte this_clock_freq_mhz; | ///< selected clock frequency
00025 };

### 26 File Documentation

# Index

ALARM_COOLDOWN_MS
defines.h, 18
ALARM_TOGGLE_FREQ
defines.h, 18
Animation, 5
Animation, 6
enter_deep_sleep, 6
enter_sentry, 6
exit_alarm, 6
gpio, 7
in_alarm, 6
in_attention, 7
in_sentry, 7
led_state, 7
timing, 7
ATTENTION_COOLDOWN_MS
defines.h, 18

CLOCK_FREQ_MHZ
defines.h, 18

defines.h
ALARM_COOLDOWN_MS, 18
ALARM_TOGGLE_FREQ, 18
ATTENTION_COOLDOWN_MS, 18
CLOCK_FREQ_MHZ, 18
DELAY_BUTTON_DEBOUNCE_MS, 19 DELAY_PIEZO_MOVED_MS, 19
PIN_BUTTON, 19
PIN_BUZZER, 19
PIN_LED, 19
PIN_PIEZO, 19
THRESHOLD_PIEZO, 20
DELAY_BUTTON_DEBOUNCE_MS
defines.h, 19
DELAY_PIEZO_MOVED_MS
defines.h, 19

enter_deep_sleep
Animation, 6
enter_sentry
Animation, 6
exit_alarm
Animation, 6

get_millis
Timing, 13
Gpio, 8
Gpio, 9
off, 9

on, 9
set_pin, 9
setup, 11
timing, 11
toggle, 11
gpio
Animation, 7

in_alarm
Animation, 6
in_attention
Animation, 7
in_sentry
Animation, 7

led_state
Animation, 7

off
Gpio, 9
on
Gpio, 9

PIN_BUTTON
defines.h, 19
PIN_BUZZER
defines.h, 19
PIN_LED
defines.h, 19
PIN_PIEZO
defines.h, 19

set_pin
Gpio, 9
setup
Gpio, 11
src/main/Animation.cpp, 15 src/main/Animation.h, 16, 17 src/main/defines.h, 17, 20 src/main/Gpio.cpp, 21
src/main/Gpio.h, 22, 23
src/main/Timing.cpp, 23, 24 src/main/Timing.h, 24, 25

this_clock_freq_mhz
Timing, 13
THRESHOLD_PIEZO
defines.h, 20
Timing, 12
get_millis, 13
this_clock_freq_mhz, 13

### 28 INDEX

Timing, 12
wait_ms, 13
timing
Animation, 7
Gpio, 11
toggle
Gpio, 11

wait_ms
Timing, 13

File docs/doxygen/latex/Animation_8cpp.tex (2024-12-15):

\doxysection{src/main/\+Animation.cpp File Reference}
\hypertarget{Animation_8cpp}{}\label{Animation_8cpp}\index{src/main/Animation.cpp@{src/main/Animation.cpp}}

Cpp file for \doxylink{classAnimation}{Animation} class that provides functions for various animations (e.\+g.  

{\ttfamily \#include "{}Animation.\+h"{}}\newline
{\ttfamily \#include "{}Arduino.\+h"{}}\newline
{\ttfamily \#include "{}Gpio.\+h"{}}\newline
{\ttfamily \#include "{}Timing.\+h"{}}\newline
{\ttfamily \#include "{}defines.\+h"{}}\newline

\doxysubsection{Detailed Description}
Cpp file for \doxylink{classAnimation}{Animation} class that provides functions for various animations (e.\+g. 

when switching states)

\begin{DoxyAuthor}{Author}
Lukas Krämer 
\end{DoxyAuthor}

Definition in file \mbox{\hyperlink{Animation_8cpp_source}{Animation.\+cpp}}.

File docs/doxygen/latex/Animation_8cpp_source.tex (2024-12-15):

\doxysection{Animation.\+cpp}
\hypertarget{Animation_8cpp_source}{}\label{Animation_8cpp_source}\index{src/main/Animation.cpp@{src/main/Animation.cpp}}
\mbox{\hyperlink{Animation_8cpp}{Go to the documentation of this file.}}
\begin{DoxyCode}{0}
\DoxyCodeLine{\Hypertarget{Animation_8cpp_source_l00001}00001\ \textcolor{comment}{/**}}
\DoxyCodeLine{\Hypertarget{Animation_8cpp_source_l00002}00002\ \textcolor{comment}{\ *\ @file\ Animation.cpp}}
\DoxyCodeLine{\Hypertarget{Animation_8cpp_source_l00003}00003\ \textcolor{comment}{\ *}}
\DoxyCodeLine{\Hypertarget{Animation_8cpp_source_l00004}00004\ \textcolor{comment}{\ *\ Cpp\ file\ for\ Animation\ class\ that\ provides}}
\DoxyCodeLine{\Hypertarget{Animation_8cpp_source_l00005}00005\ \textcolor{comment}{\ *\ functions\ for\ various\ animations\ (e.g.\ when\ switching\ states)}}
\DoxyCodeLine{\Hypertarget{Animation_8cpp_source_l00006}00006\ \textcolor{comment}{\ *}}
\DoxyCodeLine{\Hypertarget{Animation_8cpp_source_l00007}00007\ \textcolor{comment}{\ *\ @author\ Lukas\ Krämer}}
\DoxyCodeLine{\Hypertarget{Animation_8cpp_source_l00008}00008\ \textcolor{comment}{\ */}}
\DoxyCodeLine{\Hypertarget{Animation_8cpp_source_l00009}00009\ \textcolor{preprocessor}{\#pragma\ once}}
\DoxyCodeLine{\Hypertarget{Animation_8cpp_source_l00010}00010\ }
\DoxyCodeLine{\Hypertarget{Animation_8cpp_source_l00011}00011\ \textcolor{preprocessor}{\#include\ "{}\mbox{\hyperlink{Animation_8h}{Animation.h}}"{}}}
\DoxyCodeLine{\Hypertarget{Animation_8cpp_source_l00012}00012\ }
\DoxyCodeLine{\Hypertarget{Animation_8cpp_source_l00013}00013\ \textcolor{preprocessor}{\#include\ "{}Arduino.h"{}}}
\DoxyCodeLine{\Hypertarget{Animation_8cpp_source_l00014}00014\ \textcolor{preprocessor}{\#include\ "{}\mbox{\hyperlink{Gpio_8h}{Gpio.h}}"{}}}
\DoxyCodeLine{\Hypertarget{Animation_8cpp_source_l00015}00015\ \textcolor{preprocessor}{\#include\ "{}\mbox{\hyperlink{Timing_8h}{Timing.h}}"{}}}
\DoxyCodeLine{\Hypertarget{Animation_8cpp_source_l00016}00016\ \textcolor{preprocessor}{\#include\ "{}\mbox{\hyperlink{defines_8h}{defines.h}}"{}}}
\DoxyCodeLine{\Hypertarget{Animation_8cpp_source_l00017}00017\ \textcolor{comment}{}}
\DoxyCodeLine{\Hypertarget{Animation_8cpp_source_l00018}00018\ \textcolor{comment}{/**}}
\DoxyCodeLine{\Hypertarget{Animation_8cpp_source_l00019}00019\ \textcolor{comment}{\ *\ Constructor\ for\ Animation\ class.}}
\DoxyCodeLine{\Hypertarget{Animation_8cpp_source_l00020}00020\ \textcolor{comment}{\ */}}
\DoxyCodeLine{\Hypertarget{Animation_8cpp_source_l00021}\mbox{\hyperlink{classAnimation_a83f0a16cef7117f187ad596de38dd9d6}{00021}}\ \mbox{\hyperlink{classAnimation_a83f0a16cef7117f187ad596de38dd9d6}{Animation::Animation}}()\ :\ timing(\mbox{\hyperlink{defines_8h_a28a3e5097d1f1cac1cd73737434760dc}{CLOCK\_FREQ\_MHZ}}),\ gpio()\ \{}
\DoxyCodeLine{\Hypertarget{Animation_8cpp_source_l00022}00022\ \ \ \ \ \mbox{\hyperlink{classAnimation_a5a558b6ddc2bcbf7cd1f85f02dbcefd8}{gpio}}.\mbox{\hyperlink{classGpio_a5bee528b0f527ee311016b90737b1a2e}{setup}}();}
\DoxyCodeLine{\Hypertarget{Animation_8cpp_source_l00023}00023\ \ \ \ \ \mbox{\hyperlink{classAnimation_a39e733801a30c8c0dc58b4beb31ca287}{led\_state}}\ =\ \textcolor{keyword}{false};}
\DoxyCodeLine{\Hypertarget{Animation_8cpp_source_l00024}00024\ \}}
\DoxyCodeLine{\Hypertarget{Animation_8cpp_source_l00025}00025\ \textcolor{comment}{}}
\DoxyCodeLine{\Hypertarget{Animation_8cpp_source_l00026}00026\ \textcolor{comment}{/**}}
\DoxyCodeLine{\Hypertarget{Animation_8cpp_source_l00027}00027\ \textcolor{comment}{\ *\ Animation\ to\ play\ when\ enterying\ sentry\ state.}}
\DoxyCodeLine{\Hypertarget{Animation_8cpp_source_l00028}00028\ \textcolor{comment}{\ *}}
\DoxyCodeLine{\Hypertarget{Animation_8cpp_source_l00029}00029\ \textcolor{comment}{\ */}}
\DoxyCodeLine{\Hypertarget{Animation_8cpp_source_l00030}\mbox{\hyperlink{classAnimation_ac5c2f4f8734baec887df571960ce7517}{00030}}\ \textcolor{keywordtype}{void}\ \mbox{\hyperlink{classAnimation_ac5c2f4f8734baec887df571960ce7517}{Animation::enter\_sentry}}()\ \{}
\DoxyCodeLine{\Hypertarget{Animation_8cpp_source_l00031}00031\ \ \ \ \ \mbox{\hyperlink{classAnimation_a5a558b6ddc2bcbf7cd1f85f02dbcefd8}{gpio}}.\mbox{\hyperlink{classGpio_a0d660b06ca9c13b5171d19c33ddad8ad}{toggle}}(\mbox{\hyperlink{defines_8h_ae70934b3338990d4a3faecf2ee172d92}{PIN\_LED}},\ 3,\ 100);}
\DoxyCodeLine{\Hypertarget{Animation_8cpp_source_l00032}00032\ \}}
\DoxyCodeLine{\Hypertarget{Animation_8cpp_source_l00033}00033\ \textcolor{comment}{}}
\DoxyCodeLine{\Hypertarget{Animation_8cpp_source_l00034}00034\ \textcolor{comment}{/**}}
\DoxyCodeLine{\Hypertarget{Animation_8cpp_source_l00035}00035\ \textcolor{comment}{\ *\ Animation\ to\ play\ when\ enterying\ deep\ sleep\ state.}}
\DoxyCodeLine{\Hypertarget{Animation_8cpp_source_l00036}00036\ \textcolor{comment}{\ *}}
\DoxyCodeLine{\Hypertarget{Animation_8cpp_source_l00037}00037\ \textcolor{comment}{\ */}}
\DoxyCodeLine{\Hypertarget{Animation_8cpp_source_l00038}\mbox{\hyperlink{classAnimation_ac7681c6f56983c668054f1c66abaa53d}{00038}}\ \textcolor{keywordtype}{void}\ \mbox{\hyperlink{classAnimation_ac7681c6f56983c668054f1c66abaa53d}{Animation::enter\_deep\_sleep}}()\ \{}
\DoxyCodeLine{\Hypertarget{Animation_8cpp_source_l00039}00039\ \ \ \ \ \mbox{\hyperlink{classAnimation_a5a558b6ddc2bcbf7cd1f85f02dbcefd8}{gpio}}.\mbox{\hyperlink{classGpio_a0d660b06ca9c13b5171d19c33ddad8ad}{toggle}}(\mbox{\hyperlink{defines_8h_ae70934b3338990d4a3faecf2ee172d92}{PIN\_LED}},\ 2,\ 400);}
\DoxyCodeLine{\Hypertarget{Animation_8cpp_source_l00040}00040\ \}}
\DoxyCodeLine{\Hypertarget{Animation_8cpp_source_l00041}00041\ \textcolor{comment}{}}
\DoxyCodeLine{\Hypertarget{Animation_8cpp_source_l00042}00042\ \textcolor{comment}{/**}}
\DoxyCodeLine{\Hypertarget{Animation_8cpp_source_l00043}00043\ \textcolor{comment}{\ *\ Animation\ to\ play\ when\ in\ sentry\ mode.}}
\DoxyCodeLine{\Hypertarget{Animation_8cpp_source_l00044}00044\ \textcolor{comment}{\ *}}
\DoxyCodeLine{\Hypertarget{Animation_8cpp_source_l00045}00045\ \textcolor{comment}{\ */}}
\DoxyCodeLine{\Hypertarget{Animation_8cpp_source_l00046}\mbox{\hyperlink{classAnimation_a4c8022777b74e3f645bb147035a72ad9}{00046}}\ \textcolor{keywordtype}{void}\ \mbox{\hyperlink{classAnimation_a4c8022777b74e3f645bb147035a72ad9}{Animation::in\_sentry}}()\ \{}
\DoxyCodeLine{\Hypertarget{Animation_8cpp_source_l00047}00047\ \ \ \ \ \mbox{\hyperlink{classAnimation_a5a558b6ddc2bcbf7cd1f85f02dbcefd8}{gpio}}.\mbox{\hyperlink{classGpio_aaa1d8c4c96c48c6635498dc265feb9f2}{off}}(\mbox{\hyperlink{defines_8h_ae70934b3338990d4a3faecf2ee172d92}{PIN\_LED}});}
\DoxyCodeLine{\Hypertarget{Animation_8cpp_source_l00048}00048\ \}}
\DoxyCodeLine{\Hypertarget{Animation_8cpp_source_l00049}00049\ \textcolor{comment}{}}
\DoxyCodeLine{\Hypertarget{Animation_8cpp_source_l00050}00050\ \textcolor{comment}{/**}}
\DoxyCodeLine{\Hypertarget{Animation_8cpp_source_l00051}00051\ \textcolor{comment}{\ *\ Animation\ to\ play\ when\ in\ attention\ mode.}}
\DoxyCodeLine{\Hypertarget{Animation_8cpp_source_l00052}00052\ \textcolor{comment}{\ *}}
\DoxyCodeLine{\Hypertarget{Animation_8cpp_source_l00053}00053\ \textcolor{comment}{\ */}}
\DoxyCodeLine{\Hypertarget{Animation_8cpp_source_l00054}\mbox{\hyperlink{classAnimation_a655dfc67ade58898fe2fbcbc4b0b36b4}{00054}}\ \textcolor{keywordtype}{void}\ \mbox{\hyperlink{classAnimation_a655dfc67ade58898fe2fbcbc4b0b36b4}{Animation::in\_attention}}()\ \{}
\DoxyCodeLine{\Hypertarget{Animation_8cpp_source_l00055}00055\ \ \ \ \ \mbox{\hyperlink{classAnimation_a5a558b6ddc2bcbf7cd1f85f02dbcefd8}{gpio}}.\mbox{\hyperlink{classGpio_a8e7d8257872d8e9768e79ee92ccad76f}{on}}(\mbox{\hyperlink{defines_8h_ae70934b3338990d4a3faecf2ee172d92}{PIN\_LED}});}
\DoxyCodeLine{\Hypertarget{Animation_8cpp_source_l00056}00056\ \}}
\DoxyCodeLine{\Hypertarget{Animation_8cpp_source_l00057}00057\ \textcolor{comment}{}}
\DoxyCodeLine{\Hypertarget{Animation_8cpp_source_l00058}00058\ \textcolor{comment}{/**}}
\DoxyCodeLine{\Hypertarget{Animation_8cpp_source_l00059}00059\ \textcolor{comment}{\ *\ Animation\ to\ play\ when\ exiting\ alarm\ mode.}}
\DoxyCodeLine{\Hypertarget{Animation_8cpp_source_l00060}00060\ \textcolor{comment}{\ *}}
\DoxyCodeLine{\Hypertarget{Animation_8cpp_source_l00061}00061\ \textcolor{comment}{\ */}}
\DoxyCodeLine{\Hypertarget{Animation_8cpp_source_l00062}\mbox{\hyperlink{classAnimation_a55d2a7631800340baf2753fcf2a5a4c3}{00062}}\ \textcolor{keywordtype}{void}\ \mbox{\hyperlink{classAnimation_a55d2a7631800340baf2753fcf2a5a4c3}{Animation::exit\_alarm}}()\ \{}
\DoxyCodeLine{\Hypertarget{Animation_8cpp_source_l00063}00063\ \ \ \ \ \mbox{\hyperlink{classAnimation_a5a558b6ddc2bcbf7cd1f85f02dbcefd8}{gpio}}.\mbox{\hyperlink{classGpio_aaa1d8c4c96c48c6635498dc265feb9f2}{off}}(\mbox{\hyperlink{defines_8h_ae70934b3338990d4a3faecf2ee172d92}{PIN\_LED}});}
\DoxyCodeLine{\Hypertarget{Animation_8cpp_source_l00064}00064\ \ \ \ \ \mbox{\hyperlink{classAnimation_a5a558b6ddc2bcbf7cd1f85f02dbcefd8}{gpio}}.\mbox{\hyperlink{classGpio_aaa1d8c4c96c48c6635498dc265feb9f2}{off}}(\mbox{\hyperlink{defines_8h_a192ea8eaba652d29bfc08675edebb6a2}{PIN\_BUZZER}});}
\DoxyCodeLine{\Hypertarget{Animation_8cpp_source_l00065}00065\ \}}
\DoxyCodeLine{\Hypertarget{Animation_8cpp_source_l00066}00066\ \textcolor{comment}{}}
\DoxyCodeLine{\Hypertarget{Animation_8cpp_source_l00067}00067\ \textcolor{comment}{/**}}
\DoxyCodeLine{\Hypertarget{Animation_8cpp_source_l00068}00068\ \textcolor{comment}{\ *\ Animation\ to\ play\ when\ in\ alarm\ mode.}}
\DoxyCodeLine{\Hypertarget{Animation_8cpp_source_l00069}00069\ \textcolor{comment}{\ *}}
\DoxyCodeLine{\Hypertarget{Animation_8cpp_source_l00070}00070\ \textcolor{comment}{\ */}}
\DoxyCodeLine{\Hypertarget{Animation_8cpp_source_l00071}\mbox{\hyperlink{classAnimation_a18b6277f0fbb999535d20da6f5c7a98a}{00071}}\ \textcolor{keywordtype}{void}\ \mbox{\hyperlink{classAnimation_a18b6277f0fbb999535d20da6f5c7a98a}{Animation::in\_alarm}}()\ \{}
\DoxyCodeLine{\Hypertarget{Animation_8cpp_source_l00072}00072\ \ \ \ \ \mbox{\hyperlink{classAnimation_a5a558b6ddc2bcbf7cd1f85f02dbcefd8}{gpio}}.\mbox{\hyperlink{classGpio_ad62c668ecc91f404fc7efc15833fecf8}{set\_pin}}(\mbox{\hyperlink{defines_8h_ae70934b3338990d4a3faecf2ee172d92}{PIN\_LED}},\ \mbox{\hyperlink{classAnimation_a39e733801a30c8c0dc58b4beb31ca287}{led\_state}});}
\DoxyCodeLine{\Hypertarget{Animation_8cpp_source_l00073}00073\ \ \ \ \ \mbox{\hyperlink{classAnimation_a5a558b6ddc2bcbf7cd1f85f02dbcefd8}{gpio}}.\mbox{\hyperlink{classGpio_ad62c668ecc91f404fc7efc15833fecf8}{set\_pin}}(\mbox{\hyperlink{defines_8h_a192ea8eaba652d29bfc08675edebb6a2}{PIN\_BUZZER}},\ !\mbox{\hyperlink{classAnimation_a39e733801a30c8c0dc58b4beb31ca287}{led\_state}});}
\DoxyCodeLine{\Hypertarget{Animation_8cpp_source_l00074}00074\ \ \ \ \ \mbox{\hyperlink{classAnimation_a39e733801a30c8c0dc58b4beb31ca287}{led\_state}}\ =\ !\mbox{\hyperlink{classAnimation_a39e733801a30c8c0dc58b4beb31ca287}{led\_state}};}
\DoxyCodeLine{\Hypertarget{Animation_8cpp_source_l00075}00075\ \}}

\end{DoxyCode}

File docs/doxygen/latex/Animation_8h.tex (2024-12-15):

\doxysection{src/main/\+Animation.h File Reference}
\hypertarget{Animation_8h}{}\label{Animation_8h}\index{src/main/Animation.h@{src/main/Animation.h}}

Header file for \doxylink{classAnimation}{Animation} class.  

{\ttfamily \#include "{}Arduino.\+h"{}}\newline
{\ttfamily \#include "{}Gpio.\+h"{}}\newline
{\ttfamily \#include "{}Timing.\+h"{}}\newline
{\ttfamily \#include "{}defines.\+h"{}}\newline
\doxysubsubsection*{Data Structures}
\begin{DoxyCompactItemize}
\item 
class \mbox{\hyperlink{classAnimation}{Animation}}
\begin{DoxyCompactList}\small\item\em \doxylink{classAnimation}{Animation} class that provides functions for various animations (e.\+g. \end{DoxyCompactList}\end{DoxyCompactItemize}

\doxysubsection{Detailed Description}
Header file for \doxylink{classAnimation}{Animation} class. 

\begin{DoxyAuthor}{Author}
Lukas Krämer 
\end{DoxyAuthor}

Definition in file \mbox{\hyperlink{Animation_8h_source}{Animation.\+h}}.

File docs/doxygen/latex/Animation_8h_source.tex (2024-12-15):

\doxysection{Animation.\+h}
\hypertarget{Animation_8h_source}{}\label{Animation_8h_source}\index{src/main/Animation.h@{src/main/Animation.h}}
\mbox{\hyperlink{Animation_8h}{Go to the documentation of this file.}}
\begin{DoxyCode}{0}
\DoxyCodeLine{\Hypertarget{Animation_8h_source_l00001}00001\ \textcolor{comment}{/**}}
\DoxyCodeLine{\Hypertarget{Animation_8h_source_l00002}00002\ \textcolor{comment}{\ *\ @file\ Animation.h}}
\DoxyCodeLine{\Hypertarget{Animation_8h_source_l00003}00003\ \textcolor{comment}{\ *}}
\DoxyCodeLine{\Hypertarget{Animation_8h_source_l00004}00004\ \textcolor{comment}{\ *\ Header\ file\ for\ Animation\ class}}
\DoxyCodeLine{\Hypertarget{Animation_8h_source_l00005}00005\ \textcolor{comment}{\ *}}
\DoxyCodeLine{\Hypertarget{Animation_8h_source_l00006}00006\ \textcolor{comment}{\ *\ @author\ Lukas\ Krämer}}
\DoxyCodeLine{\Hypertarget{Animation_8h_source_l00007}00007\ \textcolor{comment}{\ */}}
\DoxyCodeLine{\Hypertarget{Animation_8h_source_l00008}00008\ \textcolor{preprocessor}{\#pragma\ once}}
\DoxyCodeLine{\Hypertarget{Animation_8h_source_l00009}00009\ }
\DoxyCodeLine{\Hypertarget{Animation_8h_source_l00010}00010\ \textcolor{preprocessor}{\#include\ "{}Arduino.h"{}}}
\DoxyCodeLine{\Hypertarget{Animation_8h_source_l00011}00011\ \textcolor{preprocessor}{\#include\ "{}\mbox{\hyperlink{Gpio_8h}{Gpio.h}}"{}}}
\DoxyCodeLine{\Hypertarget{Animation_8h_source_l00012}00012\ \textcolor{preprocessor}{\#include\ "{}\mbox{\hyperlink{Timing_8h}{Timing.h}}"{}}}
\DoxyCodeLine{\Hypertarget{Animation_8h_source_l00013}00013\ \textcolor{preprocessor}{\#include\ "{}\mbox{\hyperlink{defines_8h}{defines.h}}"{}}}
\DoxyCodeLine{\Hypertarget{Animation_8h_source_l00014}00014\ \textcolor{comment}{}}
\DoxyCodeLine{\Hypertarget{Animation_8h_source_l00015}00015\ \textcolor{comment}{/**}}
\DoxyCodeLine{\Hypertarget{Animation_8h_source_l00016}00016\ \textcolor{comment}{\ *\ Animation\ class\ that\ provides}}
\DoxyCodeLine{\Hypertarget{Animation_8h_source_l00017}00017\ \textcolor{comment}{\ *\ functions\ for\ various\ animations\ (e.g.\ when\ switching\ states)}}
\DoxyCodeLine{\Hypertarget{Animation_8h_source_l00018}00018\ \textcolor{comment}{\ *}}
\DoxyCodeLine{\Hypertarget{Animation_8h_source_l00019}00019\ \textcolor{comment}{\ */}}
\DoxyCodeLine{\Hypertarget{Animation_8h_source_l00020}\mbox{\hyperlink{classAnimation}{00020}}\ \textcolor{keyword}{class\ }\mbox{\hyperlink{classAnimation}{Animation}}\ \{}
\DoxyCodeLine{\Hypertarget{Animation_8h_source_l00021}00021\ \ \ \ \textcolor{keyword}{public}:}
\DoxyCodeLine{\Hypertarget{Animation_8h_source_l00022}00022\ \ \ \ \ \mbox{\hyperlink{classAnimation_a83f0a16cef7117f187ad596de38dd9d6}{Animation}}();}
\DoxyCodeLine{\Hypertarget{Animation_8h_source_l00023}00023\ \ \ \ \ \textcolor{keywordtype}{void}\ \mbox{\hyperlink{classAnimation_ac5c2f4f8734baec887df571960ce7517}{enter\_sentry}}();}
\DoxyCodeLine{\Hypertarget{Animation_8h_source_l00024}00024\ \ \ \ \ \textcolor{keywordtype}{void}\ \mbox{\hyperlink{classAnimation_ac7681c6f56983c668054f1c66abaa53d}{enter\_deep\_sleep}}();}
\DoxyCodeLine{\Hypertarget{Animation_8h_source_l00025}00025\ \ \ \ \ \textcolor{keywordtype}{void}\ \mbox{\hyperlink{classAnimation_a4c8022777b74e3f645bb147035a72ad9}{in\_sentry}}();}
\DoxyCodeLine{\Hypertarget{Animation_8h_source_l00026}00026\ \ \ \ \ \textcolor{keywordtype}{void}\ \mbox{\hyperlink{classAnimation_a655dfc67ade58898fe2fbcbc4b0b36b4}{in\_attention}}();}
\DoxyCodeLine{\Hypertarget{Animation_8h_source_l00027}00027\ \ \ \ \ \textcolor{keywordtype}{void}\ \mbox{\hyperlink{classAnimation_a55d2a7631800340baf2753fcf2a5a4c3}{exit\_alarm}}();}
\DoxyCodeLine{\Hypertarget{Animation_8h_source_l00028}00028\ \ \ \ \ \textcolor{keywordtype}{void}\ \mbox{\hyperlink{classAnimation_a18b6277f0fbb999535d20da6f5c7a98a}{in\_alarm}}();}
\DoxyCodeLine{\Hypertarget{Animation_8h_source_l00029}00029\ }
\DoxyCodeLine{\Hypertarget{Animation_8h_source_l00030}00030\ \ \ \ \textcolor{keyword}{private}:}
\DoxyCodeLine{\Hypertarget{Animation_8h_source_l00031}\mbox{\hyperlink{classAnimation_a12d9d1b4db91738e8468f048152b202f}{00031}}\ \ \ \ \ \mbox{\hyperlink{classTiming}{Timing}}\ \mbox{\hyperlink{classAnimation_a12d9d1b4db91738e8468f048152b202f}{timing}};\ \ \ \textcolor{comment}{///<\ Timing\ instance}}
\DoxyCodeLine{\Hypertarget{Animation_8h_source_l00032}\mbox{\hyperlink{classAnimation_a5a558b6ddc2bcbf7cd1f85f02dbcefd8}{00032}}\ \ \ \ \ \mbox{\hyperlink{classGpio}{Gpio}}\ \mbox{\hyperlink{classAnimation_a5a558b6ddc2bcbf7cd1f85f02dbcefd8}{gpio}};\ \ \ \ \ \ \ \textcolor{comment}{///<\ GPIO\ instance}}
\DoxyCodeLine{\Hypertarget{Animation_8h_source_l00033}\mbox{\hyperlink{classAnimation_a39e733801a30c8c0dc58b4beb31ca287}{00033}}\ \ \ \ \ \textcolor{keywordtype}{bool}\ \mbox{\hyperlink{classAnimation_a39e733801a30c8c0dc58b4beb31ca287}{led\_state}};\ \ \textcolor{comment}{///<\ current\ led\ state\ in\ alarm}}
\DoxyCodeLine{\Hypertarget{Animation_8h_source_l00034}00034\ \};}

\end{DoxyCode}

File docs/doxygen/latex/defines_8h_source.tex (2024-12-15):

\doxysection{defines.\+h}
\hypertarget{defines_8h_source}{}\label{defines_8h_source}\index{src/main/defines.h@{src/main/defines.h}}
\mbox{\hyperlink{defines_8h}{Go to the documentation of this file.}}
\begin{DoxyCode}{0}
\DoxyCodeLine{\Hypertarget{defines_8h_source_l00001}00001\ \textcolor{comment}{/**}}
\DoxyCodeLine{\Hypertarget{defines_8h_source_l00002}00002\ \textcolor{comment}{\ *\ @file\ defines.h}}
\DoxyCodeLine{\Hypertarget{defines_8h_source_l00003}00003\ \textcolor{comment}{\ *}}
\DoxyCodeLine{\Hypertarget{defines_8h_source_l00004}00004\ \textcolor{comment}{\ *\ This\ file\ includes\ all\ important\ declarations\ and\ definitions.}}
\DoxyCodeLine{\Hypertarget{defines_8h_source_l00005}00005\ \textcolor{comment}{\ *}}
\DoxyCodeLine{\Hypertarget{defines_8h_source_l00006}00006\ \textcolor{comment}{\ *\ @author\ Lukas\ Krämer}}
\DoxyCodeLine{\Hypertarget{defines_8h_source_l00007}00007\ \textcolor{comment}{\ */}}
\DoxyCodeLine{\Hypertarget{defines_8h_source_l00008}00008\ \textcolor{comment}{}}
\DoxyCodeLine{\Hypertarget{defines_8h_source_l00009}00009\ \textcolor{comment}{/**}}
\DoxyCodeLine{\Hypertarget{defines_8h_source_l00010}00010\ \textcolor{comment}{\ *\ @brief\ Pin\ for\ the\ LED.}}
\DoxyCodeLine{\Hypertarget{defines_8h_source_l00011}00011\ \textcolor{comment}{\ */}}
\DoxyCodeLine{\Hypertarget{defines_8h_source_l00012}\mbox{\hyperlink{defines_8h_ae70934b3338990d4a3faecf2ee172d92}{00012}}\ \textcolor{preprocessor}{\#define\ PIN\_LED\ 1}}
\DoxyCodeLine{\Hypertarget{defines_8h_source_l00013}00013\ \textcolor{comment}{}}
\DoxyCodeLine{\Hypertarget{defines_8h_source_l00014}00014\ \textcolor{comment}{/**}}
\DoxyCodeLine{\Hypertarget{defines_8h_source_l00015}00015\ \textcolor{comment}{\ *\ @brief\ Pin\ for\ the\ button.}}
\DoxyCodeLine{\Hypertarget{defines_8h_source_l00016}00016\ \textcolor{comment}{\ */}}
\DoxyCodeLine{\Hypertarget{defines_8h_source_l00017}\mbox{\hyperlink{defines_8h_a3be8154d350ce65f5e6c1dfc284700af}{00017}}\ \textcolor{preprocessor}{\#define\ PIN\_BUTTON\ 2}}
\DoxyCodeLine{\Hypertarget{defines_8h_source_l00018}00018\ \textcolor{comment}{}}
\DoxyCodeLine{\Hypertarget{defines_8h_source_l00019}00019\ \textcolor{comment}{/**}}
\DoxyCodeLine{\Hypertarget{defines_8h_source_l00020}00020\ \textcolor{comment}{\ *\ @brief\ Pin\ for\ the\ piezo.}}
\DoxyCodeLine{\Hypertarget{defines_8h_source_l00021}00021\ \textcolor{comment}{\ */}}
\DoxyCodeLine{\Hypertarget{defines_8h_source_l00022}\mbox{\hyperlink{defines_8h_ad67197684098f7e8191189a49b5198cd}{00022}}\ \textcolor{preprocessor}{\#define\ PIN\_PIEZO\ 3}}
\DoxyCodeLine{\Hypertarget{defines_8h_source_l00023}00023\ \textcolor{comment}{}}
\DoxyCodeLine{\Hypertarget{defines_8h_source_l00024}00024\ \textcolor{comment}{/**}}
\DoxyCodeLine{\Hypertarget{defines_8h_source_l00025}00025\ \textcolor{comment}{\ *\ @brief\ Pin\ for\ the\ button.}}
\DoxyCodeLine{\Hypertarget{defines_8h_source_l00026}00026\ \textcolor{comment}{\ */}}
\DoxyCodeLine{\Hypertarget{defines_8h_source_l00027}\mbox{\hyperlink{defines_8h_a192ea8eaba652d29bfc08675edebb6a2}{00027}}\ \textcolor{preprocessor}{\#define\ PIN\_BUZZER\ 4}}
\DoxyCodeLine{\Hypertarget{defines_8h_source_l00028}00028\ \textcolor{comment}{}}
\DoxyCodeLine{\Hypertarget{defines_8h_source_l00029}00029\ \textcolor{comment}{/**}}
\DoxyCodeLine{\Hypertarget{defines_8h_source_l00030}00030\ \textcolor{comment}{\ *\ @brief\ Selected\ clock\ frequency\ in\ MHz.}}
\DoxyCodeLine{\Hypertarget{defines_8h_source_l00031}00031\ \textcolor{comment}{\ */}}
\DoxyCodeLine{\Hypertarget{defines_8h_source_l00032}\mbox{\hyperlink{defines_8h_a28a3e5097d1f1cac1cd73737434760dc}{00032}}\ \textcolor{preprocessor}{\#define\ CLOCK\_FREQ\_MHZ\ 1}}
\DoxyCodeLine{\Hypertarget{defines_8h_source_l00033}00033\ \textcolor{comment}{}}
\DoxyCodeLine{\Hypertarget{defines_8h_source_l00034}00034\ \textcolor{comment}{/**}}
\DoxyCodeLine{\Hypertarget{defines_8h_source_l00035}00035\ \textcolor{comment}{\ *\ @brief\ Threshold\ for\ piezo\ for\ movement\ detection.}}
\DoxyCodeLine{\Hypertarget{defines_8h_source_l00036}00036\ \textcolor{comment}{\ */}}
\DoxyCodeLine{\Hypertarget{defines_8h_source_l00037}\mbox{\hyperlink{defines_8h_a5be5a63f189faba4da1c6f98d11310c6}{00037}}\ \textcolor{preprocessor}{\#define\ THRESHOLD\_PIEZO\ 30}}
\DoxyCodeLine{\Hypertarget{defines_8h_source_l00038}00038\ \textcolor{comment}{}}
\DoxyCodeLine{\Hypertarget{defines_8h_source_l00039}00039\ \textcolor{comment}{/**}}
\DoxyCodeLine{\Hypertarget{defines_8h_source_l00040}00040\ \textcolor{comment}{\ *\ @brief\ Button\ debounce\ delay.}}
\DoxyCodeLine{\Hypertarget{defines_8h_source_l00041}00041\ \textcolor{comment}{\ */}}
\DoxyCodeLine{\Hypertarget{defines_8h_source_l00042}\mbox{\hyperlink{defines_8h_ae8df221e4e5e1930a43fb7d2c3944665}{00042}}\ \textcolor{preprocessor}{\#define\ DELAY\_BUTTON\_DEBOUNCE\_MS\ 50}}
\DoxyCodeLine{\Hypertarget{defines_8h_source_l00043}00043\ \textcolor{comment}{}}
\DoxyCodeLine{\Hypertarget{defines_8h_source_l00044}00044\ \textcolor{comment}{/**}}
\DoxyCodeLine{\Hypertarget{defines_8h_source_l00045}00045\ \textcolor{comment}{\ *\ @brief\ Frequency\ for\ alarm.}}
\DoxyCodeLine{\Hypertarget{defines_8h_source_l00046}00046\ \textcolor{comment}{\ */}}
\DoxyCodeLine{\Hypertarget{defines_8h_source_l00047}\mbox{\hyperlink{defines_8h_a253c5c57ad2d67b9d8b6ddb553dde09a}{00047}}\ \textcolor{preprocessor}{\#define\ ALARM\_TOGGLE\_FREQ\ 20}}
\DoxyCodeLine{\Hypertarget{defines_8h_source_l00048}00048\ \textcolor{comment}{}}
\DoxyCodeLine{\Hypertarget{defines_8h_source_l00049}00049\ \textcolor{comment}{/**}}
\DoxyCodeLine{\Hypertarget{defines_8h_source_l00050}00050\ \textcolor{comment}{\ *\ @brief\ When\ piezo\ is\ moved,\ wait}}
\DoxyCodeLine{\Hypertarget{defines_8h_source_l00051}00051\ \textcolor{comment}{\ *\ for\ DELAY\_PIEZO\_MOVED\_MS\ because\ it\ could\ be\ just\ a\ button\ press.}}
\DoxyCodeLine{\Hypertarget{defines_8h_source_l00052}00052\ \textcolor{comment}{\ */}}
\DoxyCodeLine{\Hypertarget{defines_8h_source_l00053}\mbox{\hyperlink{defines_8h_a6cd671141c60a732c42f1ad79f1a5890}{00053}}\ \textcolor{preprocessor}{\#define\ DELAY\_PIEZO\_MOVED\_MS\ 500}}
\DoxyCodeLine{\Hypertarget{defines_8h_source_l00054}00054\ \textcolor{comment}{}}
\DoxyCodeLine{\Hypertarget{defines_8h_source_l00055}00055\ \textcolor{comment}{/**}}
\DoxyCodeLine{\Hypertarget{defines_8h_source_l00056}00056\ \textcolor{comment}{\ *\ @brief\ Cooldown\ after\ which\ state\ attention\ is\ left\ again.}}
\DoxyCodeLine{\Hypertarget{defines_8h_source_l00057}00057\ \textcolor{comment}{\ */}}
\DoxyCodeLine{\Hypertarget{defines_8h_source_l00058}\mbox{\hyperlink{defines_8h_a9e1a2184797108f3fd67e0251343d960}{00058}}\ \textcolor{preprocessor}{\#define\ ATTENTION\_COOLDOWN\_MS\ 5000}}
\DoxyCodeLine{\Hypertarget{defines_8h_source_l00059}00059\ \textcolor{comment}{}}
\DoxyCodeLine{\Hypertarget{defines_8h_source_l00060}00060\ \textcolor{comment}{/**}}
\DoxyCodeLine{\Hypertarget{defines_8h_source_l00061}00061\ \textcolor{comment}{\ *\ @brief\ Cooldown\ after\ which\ state\ alarm\ is\ left\ again.}}
\DoxyCodeLine{\Hypertarget{defines_8h_source_l00062}00062\ \textcolor{comment}{\ */}}
\DoxyCodeLine{\Hypertarget{defines_8h_source_l00063}\mbox{\hyperlink{defines_8h_a6b3c978dd2a7b246650bb233f2b8e942}{00063}}\ \textcolor{preprocessor}{\#define\ ALARM\_COOLDOWN\_MS\ 5000}}

\end{DoxyCode}

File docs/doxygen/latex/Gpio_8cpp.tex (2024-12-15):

\doxysection{src/main/\+Gpio.cpp File Reference}
\hypertarget{Gpio_8cpp}{}\label{Gpio_8cpp}\index{src/main/Gpio.cpp@{src/main/Gpio.cpp}}

Cpp file for \doxylink{classGpio}{Gpio} class that provides functions for direct hardware actions (e.\+g.  

{\ttfamily \#include "{}Gpio.\+h"{}}\newline
{\ttfamily \#include "{}Arduino.\+h"{}}\newline
{\ttfamily \#include "{}Timing.\+h"{}}\newline
{\ttfamily \#include "{}defines.\+h"{}}\newline

\doxysubsection{Detailed Description}
Cpp file for \doxylink{classGpio}{Gpio} class that provides functions for direct hardware actions (e.\+g. 

turning on/off digital pins)

\begin{DoxyAuthor}{Author}
Lukas Krämer 
\end{DoxyAuthor}

Definition in file \mbox{\hyperlink{Gpio_8cpp_source}{Gpio.\+cpp}}.

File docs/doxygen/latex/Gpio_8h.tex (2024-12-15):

\doxysection{src/main/\+Gpio.h File Reference}
\hypertarget{Gpio_8h}{}\label{Gpio_8h}\index{src/main/Gpio.h@{src/main/Gpio.h}}

Header file for \doxylink{classGpio}{Gpio} class.  

{\ttfamily \#include "{}Arduino.\+h"{}}\newline
{\ttfamily \#include "{}Timing.\+h"{}}\newline
{\ttfamily \#include "{}defines.\+h"{}}\newline
\doxysubsubsection*{Data Structures}
\begin{DoxyCompactItemize}
\item 
class \mbox{\hyperlink{classGpio}{Gpio}}
\begin{DoxyCompactList}\small\item\em \doxylink{classGpio}{Gpio} class that provides functions for direct hardware actions (e.\+g. \end{DoxyCompactList}\end{DoxyCompactItemize}

\doxysubsection{Detailed Description}
Header file for \doxylink{classGpio}{Gpio} class. 

\begin{DoxyAuthor}{Author}
Lukas Krämer 
\end{DoxyAuthor}

Definition in file \mbox{\hyperlink{Gpio_8h_source}{Gpio.\+h}}.

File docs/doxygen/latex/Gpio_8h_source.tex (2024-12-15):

\doxysection{Gpio.\+h}
\hypertarget{Gpio_8h_source}{}\label{Gpio_8h_source}\index{src/main/Gpio.h@{src/main/Gpio.h}}
\mbox{\hyperlink{Gpio_8h}{Go to the documentation of this file.}}
\begin{DoxyCode}{0}
\DoxyCodeLine{\Hypertarget{Gpio_8h_source_l00001}00001\ \textcolor{comment}{/**}}
\DoxyCodeLine{\Hypertarget{Gpio_8h_source_l00002}00002\ \textcolor{comment}{\ *\ @file\ Gpio.h}}
\DoxyCodeLine{\Hypertarget{Gpio_8h_source_l00003}00003\ \textcolor{comment}{\ *}}
\DoxyCodeLine{\Hypertarget{Gpio_8h_source_l00004}00004\ \textcolor{comment}{\ *\ Header\ file\ for\ Gpio\ class}}
\DoxyCodeLine{\Hypertarget{Gpio_8h_source_l00005}00005\ \textcolor{comment}{\ *}}
\DoxyCodeLine{\Hypertarget{Gpio_8h_source_l00006}00006\ \textcolor{comment}{\ *\ @author\ Lukas\ Krämer}}
\DoxyCodeLine{\Hypertarget{Gpio_8h_source_l00007}00007\ \textcolor{comment}{\ */}}
\DoxyCodeLine{\Hypertarget{Gpio_8h_source_l00008}00008\ \textcolor{preprocessor}{\#pragma\ once}}
\DoxyCodeLine{\Hypertarget{Gpio_8h_source_l00009}00009\ }
\DoxyCodeLine{\Hypertarget{Gpio_8h_source_l00010}00010\ \textcolor{preprocessor}{\#include\ "{}Arduino.h"{}}}
\DoxyCodeLine{\Hypertarget{Gpio_8h_source_l00011}00011\ \textcolor{preprocessor}{\#include\ "{}\mbox{\hyperlink{Timing_8h}{Timing.h}}"{}}}
\DoxyCodeLine{\Hypertarget{Gpio_8h_source_l00012}00012\ \textcolor{preprocessor}{\#include\ "{}\mbox{\hyperlink{defines_8h}{defines.h}}"{}}}
\DoxyCodeLine{\Hypertarget{Gpio_8h_source_l00013}00013\ \textcolor{comment}{}}
\DoxyCodeLine{\Hypertarget{Gpio_8h_source_l00014}00014\ \textcolor{comment}{/**}}
\DoxyCodeLine{\Hypertarget{Gpio_8h_source_l00015}00015\ \textcolor{comment}{\ *\ Gpio\ class\ that\ provides}}
\DoxyCodeLine{\Hypertarget{Gpio_8h_source_l00016}00016\ \textcolor{comment}{\ *\ functions\ for\ direct\ hardware\ actions\ (e.g.\ turning\ on/off\ digital\ pins)}}
\DoxyCodeLine{\Hypertarget{Gpio_8h_source_l00017}00017\ \textcolor{comment}{\ *}}
\DoxyCodeLine{\Hypertarget{Gpio_8h_source_l00018}00018\ \textcolor{comment}{\ */}}
\DoxyCodeLine{\Hypertarget{Gpio_8h_source_l00019}\mbox{\hyperlink{classGpio}{00019}}\ \textcolor{keyword}{class\ }\mbox{\hyperlink{classGpio}{Gpio}}\ \{}
\DoxyCodeLine{\Hypertarget{Gpio_8h_source_l00020}00020\ \ \ \ \textcolor{keyword}{public}:}
\DoxyCodeLine{\Hypertarget{Gpio_8h_source_l00021}00021\ \ \ \ \ \mbox{\hyperlink{classGpio_a51a72b41aabb6df62d8cb35f1b35849a}{Gpio}}();}
\DoxyCodeLine{\Hypertarget{Gpio_8h_source_l00022}00022\ \ \ \ \ \textcolor{keywordtype}{void}\ \mbox{\hyperlink{classGpio_a5bee528b0f527ee311016b90737b1a2e}{setup}}();}
\DoxyCodeLine{\Hypertarget{Gpio_8h_source_l00023}00023\ \ \ \ \ \textcolor{keywordtype}{void}\ \mbox{\hyperlink{classGpio_a8e7d8257872d8e9768e79ee92ccad76f}{on}}(\textcolor{keywordtype}{byte}\ pin);}
\DoxyCodeLine{\Hypertarget{Gpio_8h_source_l00024}00024\ \ \ \ \ \textcolor{keywordtype}{void}\ \mbox{\hyperlink{classGpio_aaa1d8c4c96c48c6635498dc265feb9f2}{off}}(\textcolor{keywordtype}{byte}\ pin);}
\DoxyCodeLine{\Hypertarget{Gpio_8h_source_l00025}00025\ \ \ \ \ \textcolor{keywordtype}{void}\ \mbox{\hyperlink{classGpio_ad62c668ecc91f404fc7efc15833fecf8}{set\_pin}}(\textcolor{keywordtype}{byte}\ pin,\ \textcolor{keywordtype}{bool}\ state);}
\DoxyCodeLine{\Hypertarget{Gpio_8h_source_l00026}00026\ \ \ \ \ \textcolor{keywordtype}{void}\ \mbox{\hyperlink{classGpio_a0d660b06ca9c13b5171d19c33ddad8ad}{toggle}}(\textcolor{keywordtype}{byte}\ pin,\ \textcolor{keywordtype}{int}\ iterations,\ \textcolor{keywordtype}{long}\ d);}
\DoxyCodeLine{\Hypertarget{Gpio_8h_source_l00027}00027\ }
\DoxyCodeLine{\Hypertarget{Gpio_8h_source_l00028}00028\ \ \ \ \textcolor{keyword}{private}:}
\DoxyCodeLine{\Hypertarget{Gpio_8h_source_l00029}\mbox{\hyperlink{classGpio_ad864b345067519caba07b12ce9425f05}{00029}}\ \ \ \ \ \mbox{\hyperlink{classTiming}{Timing}}\ \mbox{\hyperlink{classGpio_ad864b345067519caba07b12ce9425f05}{timing}};\ \ \textcolor{comment}{///<\ Timing\ instance}}
\DoxyCodeLine{\Hypertarget{Gpio_8h_source_l00030}00030\ \};}

\end{DoxyCode}

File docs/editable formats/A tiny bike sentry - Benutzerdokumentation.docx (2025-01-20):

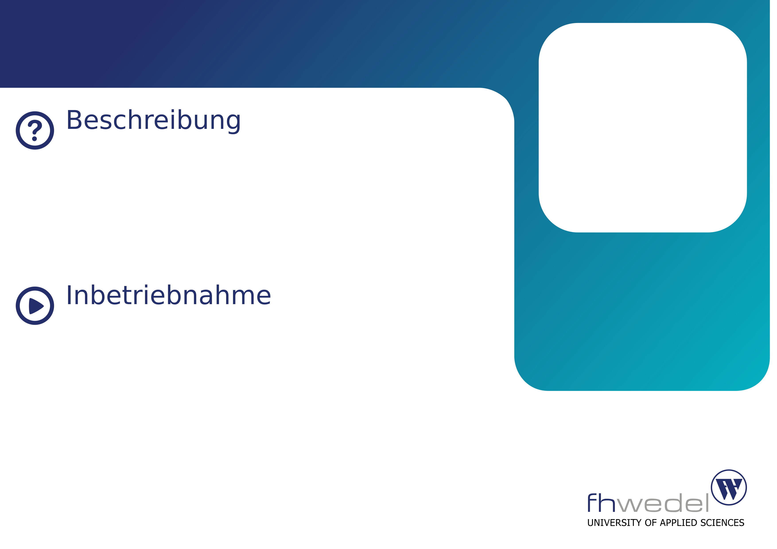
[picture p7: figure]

A tiny bike sentry - Fahrradwächter

In diesem Semester wurde ein elektronisches Fahrradschloss gebaut, was bei Erschütterungen einen Alarm auslöst und damit potentielle Diebe doch noch vom Diebstahl abschrecken soll.

3. Semester | WiSe 2024

Lukas Krämer

Das Gerät verfügt über keinen Ein- oder Ausschalter und ist automatisch im Standby Modus, sobald es mit Strom versorgt wird. Um das Schloss in Bereitschaft zu versetzen bzw. „abzuschließen“, muss der Knopf einmal gedrückt werden. Erfolgt nun eine Erschütterung, erscheint zunächst eine optische Verwarnung. Erst bei weiteren Erschütterungen wird der akustische Alarm aktiviert. Um diesen zu deaktivieren oder aus dem Bereitschaftsmodus zurück in den Schlafmodus zu kehren, muss erneut der Knopf gedrückt werden.

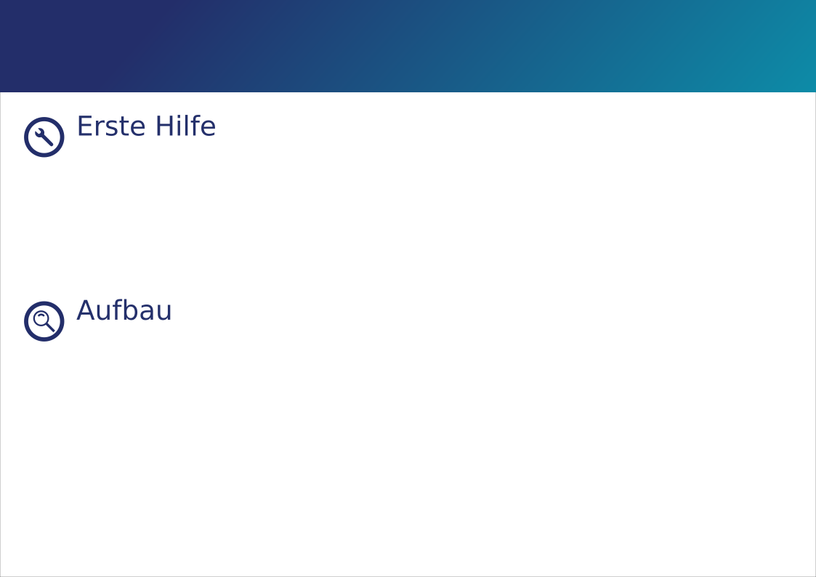
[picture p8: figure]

Ergonomische Tastatur

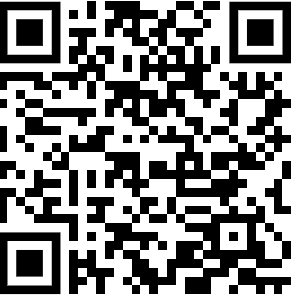
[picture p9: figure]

Prüfe zunächst, ob das Schloss mit Strom versorgt ist. Um das Schloss zu testen, muss der Knopf einmal gedrückt werden und das Gerät anschließend bewegt werden. Es sollte ein optischer und/oder akustischer Alarm folgen. Ist dies nicht der Fall, probiere das Gerät stärker zu bewegen, beispielsweise durch mäßiges Klopfen am Gehäuse.

Hilft auch das nicht weiter, liegt wahrscheinlich ein Hardware-Defekt vor und das Gerät muss fachgerecht geöffnet und repariert werden.

Das Schloss besteht im Kern aus einem kleinen und sehr stromsparenden Mikrocontroller, an den eine LED, ein kleiner Lautsprecher, ein Taster und ein Erschütterungssensor (Piezoelement) angeschlossen sind.

Befindet sich das Gerät im Bereitschaftsmodus, prüft es kontinuierlich mittels des Piezoelements, ob Erschütterungen vorliegen. Falls das der Fall ist, steuert es die LED bzw. den Buzzer an, um potenzielle Diebe abzuschrecken. Für mehr Informationen kann gerne das GitHub Repository (QR-Code) genutzt werden:

https://github.com/kraemerlukas314/A-tiny-bike-sentry

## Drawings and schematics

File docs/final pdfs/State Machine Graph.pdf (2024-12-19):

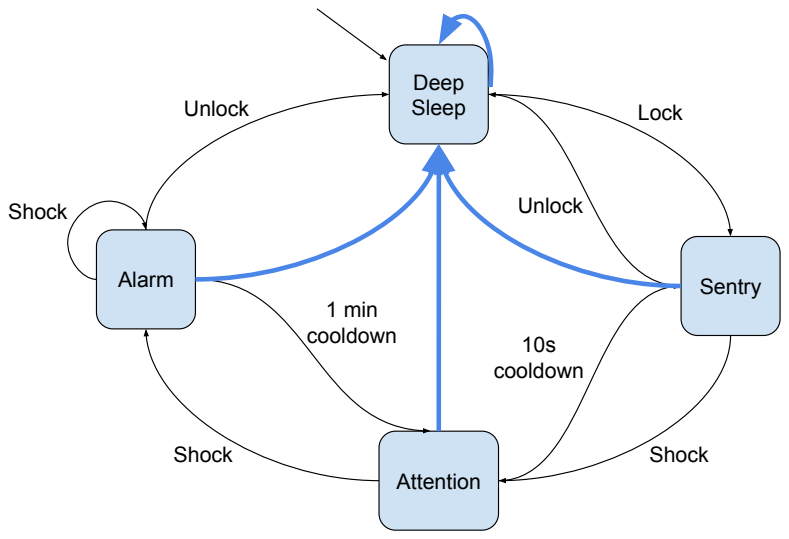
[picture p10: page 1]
Deep Sleep; Sentry; Attention; Alarm; Lock; Unlock; Shock; 10s cooldown; 1 min cooldown

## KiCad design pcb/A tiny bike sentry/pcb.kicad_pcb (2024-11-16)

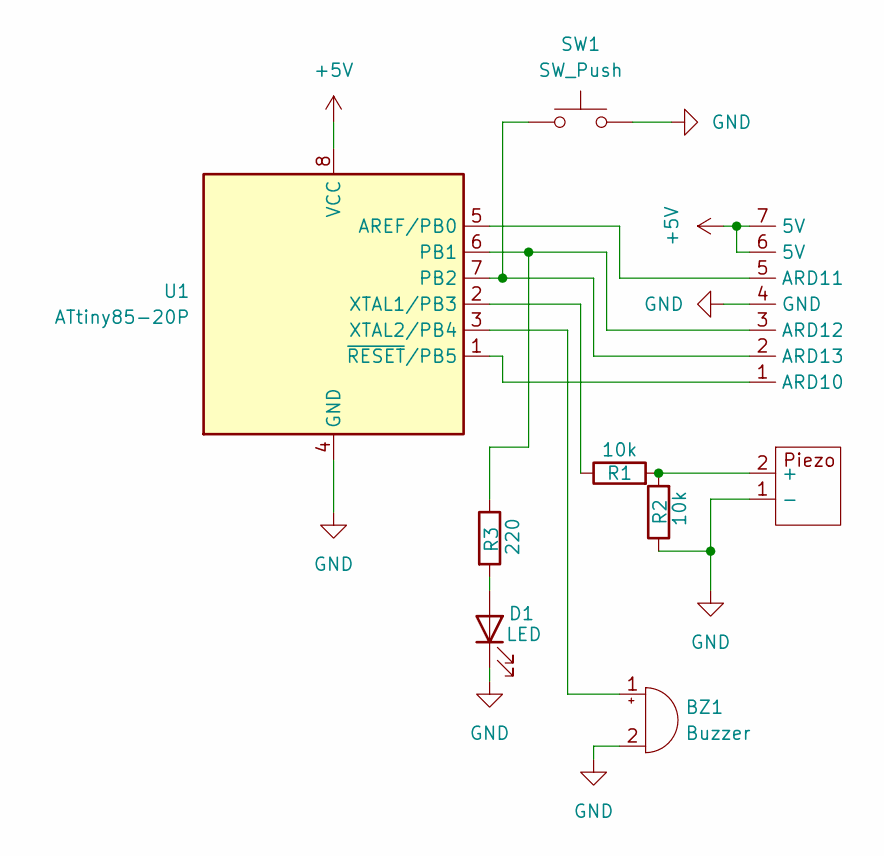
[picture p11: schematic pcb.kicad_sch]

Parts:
BZ1: Buzzer; Buzzer_15x7.5RM7.6
D1: LED; LED_D5.0mm
R1, R2: 10k; R_Axial_DIN0207_L6.3mm_D2.5mm_P10.16mm_Horizontal
R3: 220; R_Axial_DIN0207_L6.3mm_D2.5mm_P10.16mm_Horizontal
SW1: SW_Push; SW_PUSH_6mm
U1: ATtiny85-20P; DIP-8_W7.62mm
U2: Arduino_connector
U3: Piezo

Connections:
+5V: U1.8 (VCC), U2.6 (5V), U2.7 (5V)
GND: BZ1.2 (-), D1.1 (K), R2.1, SW1.2, U1.4 (GND), U2.4 (GND), U3.1 (-)
unnamed: BZ1.1 (+), U1.3 (XTAL2/PB4)
unnamed: D1.2 (A), R3.2
unnamed: U1.5 (AREF/PB0), U2.5 (ARD11)
unnamed: R3.1, U1.6 (PB1), U2.3 (ARD12)
unnamed: SW1.1, U1.7 (PB2), U2.2 (ARD13)
unnamed: R1.1, U1.2 (XTAL1/PB3)
unnamed: U1.1 (~RESET/PB5), U2.1 (ARD10)
unnamed: R1.2, R2.2, U3.2 (+)

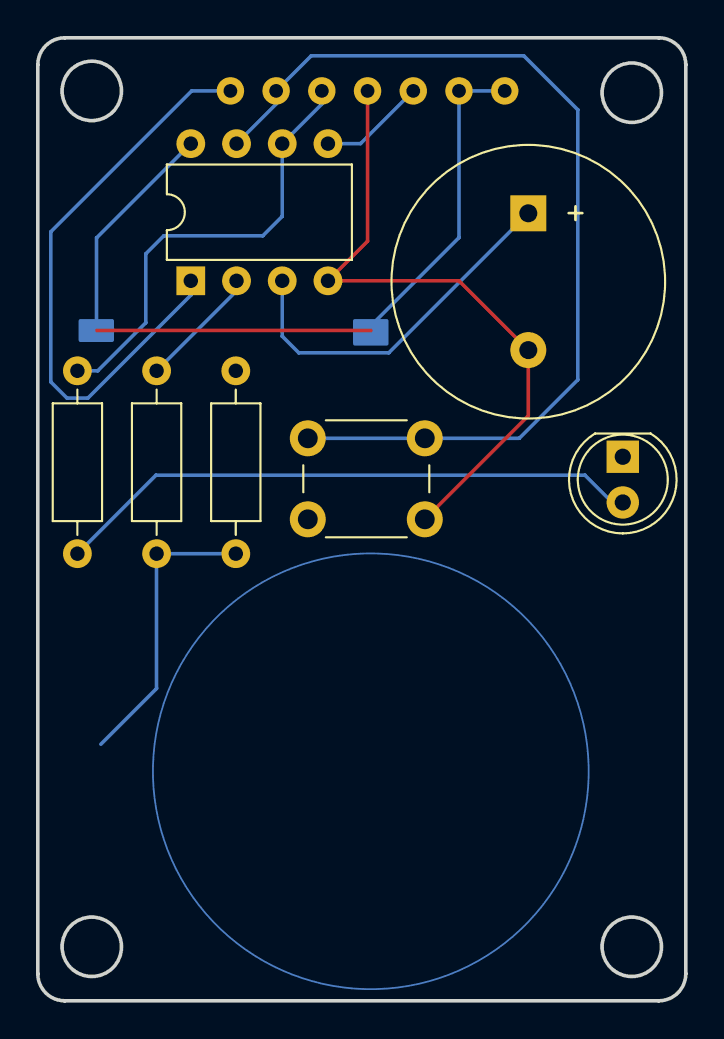
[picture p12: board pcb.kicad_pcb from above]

Board: 2 copper layers, 36.0 x 53.5 mm, 9 parts (0 on the bottom side), 10 nets.

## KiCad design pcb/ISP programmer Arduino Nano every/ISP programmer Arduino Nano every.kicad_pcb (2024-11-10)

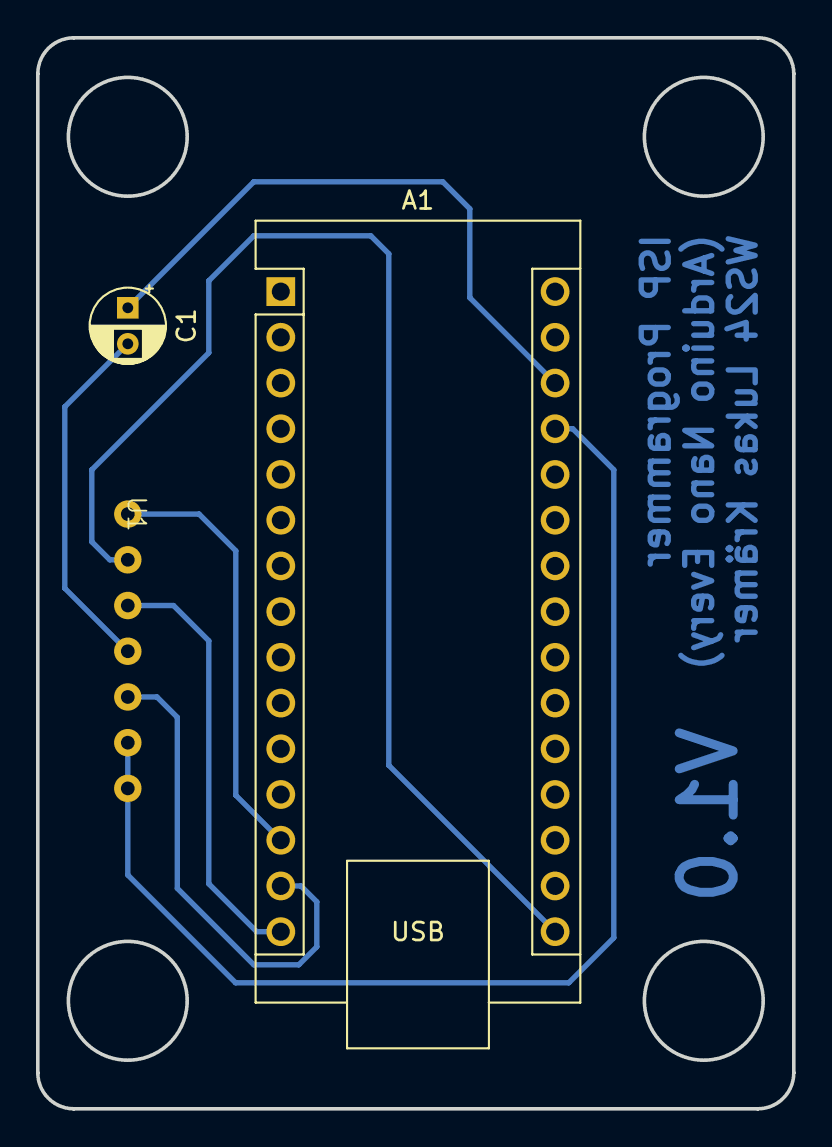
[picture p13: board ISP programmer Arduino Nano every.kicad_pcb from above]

Board: 2 copper layers, 42.0 x 59.5 mm, 3 parts (0 on the bottom side), 7 nets.

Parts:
A1: Arduino_Nano_Every; Arduino_Nano
C1: C_Polarized; CP_Radial_D4.0mm_P2.00mm
U1: Arduino_connector

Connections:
5V: A1.27 (+5V), U1.6 (5V), U1.7 (5V)
GND: A1.29 (GND), C1.2, U1.4 (GND)
unnamed: A1.13 (D10), U1.1 (ARD10)
unnamed: A1.15 (MISO), U1.3 (ARD12)
unnamed: A1.14 (MOSI), U1.5 (ARD11)
unnamed: A1.16 (SCK), U1.2 (ARD13)
unnamed: A1.28 (~RESET), C1.1

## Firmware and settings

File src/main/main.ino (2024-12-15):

/**
   @file main.ino

   This file includes all the main logic to switch between internal states
   as well as everything related to controller input (button, piezo).

   For various definitions, visit: defines.h
   For timing functions (delay, millis): Timing.cpp/Timing.h
   For GPIO control: Gpio.cpp/Gpio.h
   For Animations: Animation.cpp/Animation.h

   @author Lukas Krämer
*/

#include <avr/interrupt.h>
#include <avr/sleep.h>
#include <avr/wdt.h>

#include "Animation.h"
#include "Gpio.h"
#include "Timing.h"
#include "defines.h"

/// Enum to store current program state
enum State {
    DEEP_SLEEP,
    SENTRY,
    ATTENTION,
    ALARM
};

long long timestamp_last_led_toggle;
long long timestamp_entered_attention;
long long timestamp_entered_alarm;

State state = DEEP_SLEEP;
Gpio gpio;
Timing timing(CLOCK_FREQ_MHZ);
Animation animation;

void setup() {
    gpio.setup();

    configure_button_interrupt();
    configure_watchdog();
}

void loop() {
    wdt_reset();

    switch (state) {
        case DEEP_SLEEP:
            gpio.off(PIN_LED);
            disable_watchdog();  // Disable WDT to save power
            sleep();
            enable_watchdog();  // Re-enable WDT after waking up
            state = SENTRY;
            animation.enter_sentry();
            break;
        case SENTRY:
            animation.in_sentry();
            if (button_pressed()) {
                animation.enter_deep_sleep();
                state = DEEP_SLEEP;
            } else if (piezo_moved()) {
                timestamp_entered_attention = timing.get_millis();
                state = ATTENTION;
            }
            break;
        case ATTENTION:
            animation.in_attention();
            if (timing.get_millis() - timestamp_entered_attention > ATTENTION_COOLDOWN_MS) {
                state = SENTRY;
            }
            if (button_pressed()) {
                animation.enter_deep_sleep();
                state = DEEP_SLEEP;
            } else if (piezo_moved()) {
                timestamp_entered_alarm = timing.get_millis();
                state = ALARM;
            }
            break;
        case ALARM:
            if (timing.get_millis() - timestamp_entered_alarm > ALARM_COOLDOWN_MS) {
                animation.exit_alarm();
                timestamp_entered_attention = timing.get_millis();
                state = ATTENTION;
            }
            if (button_pressed()) {
                animation.exit_alarm();
                animation.enter_deep_sleep();
                state = DEEP_SLEEP;
            } else if (timing.get_millis() - timestamp_last_led_toggle > (1000 / ALARM_TOGGLE_FREQ)) {
                timestamp_last_led_toggle = timing.get_millis();
                animation.in_alarm();
            }
            break;
    }
}

/**
   Configures an interrupt on the specified PIN_BUTTON.
*/
void configure_button_interrupt() {
    cli();                     // Disable interrupts
    GIMSK |= _BV(PCIE);        // Enable Pin Change Interrupts
    PCMSK |= _BV(PIN_BUTTON);  // Enable interrupt on PIN_BUTTON
    sei();                     // Enable interrupts
}

/**
   Interrupt routine for waking from sleep on button press.
*/
ISR(PCINT0_vect) {
    // Handle button press interrupt
    if (!digitalRead(PIN_BUTTON)) {
        state = DEEP_SLEEP;  // Enter sleep state on button press
    }
}

/**
   Configures a watchdog timer with a timeout of four seconds.
*/
void configure_watchdog() {
    cli();  // Disable interrupts
    wdt_reset();
    WDTCR = (1 << WDP3) | (1 << WDP0);  // Set WDT timeout to 5 seconds
    WDTCR |= (1 << WDE) | (1 << WDIE);  // Enable WDT and WDT interrupt
    sei();                              // Enable interrupts
}

/**
   Enables the watchdog timer with a timeout of four seconds.
*/
void enable_watchdog() {
    cli();
    wdt_reset();
    WDTCR = (1 << WDP3) | (1 << WDP0);  // Set WDT timeout to 5 seconds
    WDTCR |= (1 << WDE) | (1 << WDIE);  // Enable WDT and WDT interrupt
    sei();
}

/**
   Disables the watchdog timer.
*/
void disable_watchdog() {
    cli();
    wdt_reset();
    WDTCR &= ~(1 << WDE);  // Disable the WDT system reset
    sei();
}

/**
   Interrupt routine for the watchdog timer.
   If watchdog triggers, enter DEEP_SLEEP state.
*/
ISR(WDT_vect) {
    // Watchdog timer interrupt: Enter sleep mode
    state = DEEP_SLEEP;
    // Re-enable button interrupt in case it was disabled
    configure_button_interrupt();
}

/**
   Returns true/false based on current button state.
   Also "debounces" the button using DELAY_BUTTON_DEBOUNCE_MS.

   @return true button is pressed
   @return false button isn't pressed
*/
bool button_pressed() {
    if (!digitalRead(PIN_BUTTON)) return false;
    gpio.off(PIN_BUZZER);
    gpio.off(PIN_LED);
    while (digitalRead(PIN_BUTTON));
    timing.wait_ms(DELAY_BUTTON_DEBOUNCE_MS);
    return true;
}

/**
   Returns true/false based on current piezo state.

   @return true piezo moved
   @return false piezo isn't moved
*/
bool piezo_moved() {
    if (analogRead(PIN_PIEZO) <= THRESHOLD_PIEZO) return false;

    long start_time = timing.get_millis();
    while (timing.get_millis() - start_time < DELAY_PIEZO_MOVED_MS) {
        if (digitalRead(PIN_BUTTON)) {
            while (digitalRead(PIN_BUTTON));
            timing.wait_ms(DELAY_BUTTON_DEBOUNCE_MS);
            return false;
        }
    }
    return true;
}

/**
   Puts ATtiny into deep sleep mode until PIN_BUTTON is pressed.
*/
void sleep() {
    while (digitalRead(PIN_BUTTON));
    timing.wait_ms(DELAY_BUTTON_DEBOUNCE_MS);
    GIMSK |= _BV(PCIE);                   // Enable Pin Change Interrupts
    PCMSK |= _BV(PIN_BUTTON);             // Use PB2 as interrupt pin
    ADCSRA &= ~_BV(ADEN);                 // ADC off
    set_sleep_mode(SLEEP_MODE_PWR_DOWN);  // Set sleep mode

    MCUCR |= (1 << BODS) | (1 << BODSE);
    MCUCR &= ~(1 << BODSE);

    ACSR |= _BV(ACD);  // Disable analog comparator

    sleep_enable();  // Enable sleep mode
    sei();           // Enable interrupts
    sleep_cpu();     // Go to sleep

    cli();                      // Disable interrupts
    PCMSK &= ~_BV(PIN_BUTTON);  // Turn off button interrupt pin
    sleep_disable();            // Clear SE bit
    ADCSRA |= _BV(ADEN);        // ADC on

    ACSR &= ~_BV(ACD);  // Re-enable Analog Comparator
    sei();              // Enable interrupts
    while (digitalRead(PIN_BUTTON));
    timing.wait_ms(DELAY_BUTTON_DEBOUNCE_MS);
}

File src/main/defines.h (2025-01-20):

/**
 * @file defines.h
 *
 * This file includes all important declarations and definitions.
 *
 * @author Lukas Krämer
 */

/**
 * @brief Pin for the LED.
 */
#define PIN_LED 1

/**
 * @brief Pin for the button.
 */
#define PIN_BUTTON 2

/**
 * @brief Pin for the piezo.
 */
#define PIN_PIEZO 3

/**
 * @brief Pin for the button.
 */
#define PIN_BUZZER 4

/**
 * @brief Selected clock frequency in MHz.
 */
#define CLOCK_FREQ_MHZ 1

/**
 * @brief Threshold for piezo for movement detection.
 */
#define THRESHOLD_PIEZO 5

/**
 * @brief Button debounce delay.
 */
#define DELAY_BUTTON_DEBOUNCE_MS 50

/**
 * @brief Frequency for alarm.
 */
#define ALARM_TOGGLE_FREQ 20

/**
 * @brief When piezo is moved, wait
 * for DELAY_PIEZO_MOVED_MS because it could be just a button press.
 */
#define DELAY_PIEZO_MOVED_MS 500

/**
 * @brief Cooldown after which state attention is left again.
 */
#define ATTENTION_COOLDOWN_MS 10000

/**
 * @brief Cooldown after which state alarm is left again.
 */
#define ALARM_COOLDOWN_MS 10000

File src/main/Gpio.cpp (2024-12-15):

/**
 * @file Gpio.cpp
 *
 * Cpp file for Gpio class that provides
 * functions for direct hardware actions (e.g. turning on/off digital pins)
 *
 * @author Lukas Krämer
 */
#pragma once

#include "Gpio.h"

#include "Arduino.h"
#include "Timing.h"
#include "defines.h"

/**
 * Constructor for Timing class.
 *
 */
Gpio::Gpio() : timing(CLOCK_FREQ_MHZ) {
    pinMode(PIN_LED, OUTPUT);
    pinMode(PIN_BUZZER, OUTPUT);
}

/**
 * GPIO setup function.
 * Sets all output pins as outputs.
 *
 */
void Gpio::setup() {
    pinMode(PIN_LED, OUTPUT);
    pinMode(PIN_BUZZER, OUTPUT);
}

/**
 * Turns on a pin.
 *
 * @param pin pin to turn on
 */
void Gpio::on(byte pin) {
    digitalWrite(pin, HIGH);
}

/**
 * Turns off a pin.
 *
 * @param pin pin to turn off
 */
void Gpio::off(byte pin) {
    digitalWrite(pin, LOW);
}

/**
 * Sets pin to state.
 *
 * @param pin pin to set state
 * @param state state to set (true/false)
 */
void Gpio::set_pin(byte pin, bool state) {
    digitalWrite(pin, state);
}

/**
 * Function to toggle a digital pin on and off.
 *
 * @param pin Pin to toggle on and off
 * @param iterations How often should pin be toggled
 * @param d delay between of/off states (d = 1 / frequency)
 */
void Gpio::toggle(byte pin, int iterations, long d) {
    for (int i = 0; i < iterations; ++i) {
        digitalWrite(pin, HIGH);
        timing.wait_ms(d);
        digitalWrite(pin, LOW);
        timing.wait_ms(d);
    }
}

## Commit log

2024-10-25 Add KiCad project
    [pcb.kicad_pcb, pcb.kicad_sch]
2024-10-26 Add schematic
    [pcb.kicad_pcb, pcb.kicad_sch]
2024-11-05 Add PCB draft
    [pcb.kicad_pcb, pcb.kicad_sch]
2024-11-06 Finish PCB design
    [pcb.kicad_pcb, pcb.kicad_sch]
2024-11-06 Add fabrication files
    [pcb.kicad_pcb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]
2024-11-10 Add ISP programmer KiCad files and gerber
    [ISP programmer Arduino Nano every-B_Cu.gbr, ISP programmer Arduino Nano every-B_Mask.gbr, ISP programmer Arduino Nano every-B_Paste.gbr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]
2024-11-16 Add basic code structure
    [pcb.kicad_pcb]
2024-11-17 Add button debouncing, fix piezo false positives
    [main.ino]
2024-11-24 Interrupts and deep sleep working
2024-12-11 Add code comments, code not working
    [main.ino]
2024-12-14 Use PIN_BUTTON as interrupt pin instead of hard coded name
2024-12-19 Add first draft of Entwicklerdokumentation
    [pcb.kicad_sch]
